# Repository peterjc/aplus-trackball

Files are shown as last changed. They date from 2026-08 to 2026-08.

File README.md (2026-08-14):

# The Ploopy A+ Trackball

The Ploopy A+ Trackball

By some stroke of luck, you've made your way here. The Ploopy A+ Trackball. Your life will never be the same.

This repository contains all of the design and production files necessary to make a Ploopy A+ Trackball. We've also included some kick-ass documentation on how to get it made, assemble it, and program it [which you can find here](https://ploopyco.github.io/aplus-trackball/).

What are you waiting for? Your new life awaits.

## QMK?!

A+ Trackballs bought from the [Ploopy store](https://ploopy.co/product-category/trackball/aplus/) come with QMK preloaded. [Check out the documentation](https://ploopyco.github.io/aplus-trackball/) for instructions on how to load new firmware onto your device. (It's super easy!)

The firmware file that ships with all A+ Trackballs is included in this repository as well, as `firmwares/aplus.uf2`.

In case you are new to the world of QMK, it is an open-source firmware for computer input peripherals. You can find the source code for all of our firmwares in [QMK's Github repository](https://github.com/ploopyco/qmk_firmware/tree/master/keyboards/ploopyco).

Note that you may have to look for specific development branches in order to find the source for all of our firmwares, as we frequently have pending pull requests.

## Under what license is this released?

As per QMK's licensing requirements, the firmware for the Ploopy A+ Trackball is released under GPLv3. Hardware design files, including electronics and mechanical files, are released under OHL CERN v2-S. Check the respective directories for full license text.

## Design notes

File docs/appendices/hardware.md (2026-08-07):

# Appendix C: Hardware

## Buying hardware from us

Getting all of the hardware on your own can be tricky because the parts you select may not fit perfectly. [That's why we sell fully-assembled A+ Trackballs](https://ploopy.co/product-category/trackball/aplus/). Here's why that's great for you:

- Everything is guaranteed to fit together perfectly
- Everything is guaranteed to work as intended
- You'll end up saving money - probably quite a bit of money - by not spending on extra parts

Your call. You'll sort it out.

## Getting your own hardware

This guide was a bit light on detail in the other sections, and that's because the hardware has to conform to many specifications. They'll all be listed here.

First, a complete list of all the hardware you'll need:

- 6x Small Screws
- 3x MR63ZZ Roller Bearings
- 2x 6700-2RS Roller Bearings
- 2x Magnet
- 4x Friction Pads
- 1x 1.75" Ball

We'll be going over all of them in detail. There will be mentions of *critical specifications*; if you're going to be sourcing your own parts, **you must get parts that conform to the critical specifications**. If you go off-menu, the parts will not fit the way that we intended when we designed the Bean. That might mean that your Bean **doesn't work**.

Let's get cracking.

### Small Screws

Here are the critical specifications:

- \#2
- 3/8" length

### MR63ZZ Roller Bearings

Here are the critical specifications:

- MR63ZZ bearing
- 3mm inner diameter
- 6mm outer diameter
- 2.5mm thickness

### 6700-2RS Roller Bearings

Here are the critical specifications:

- 6700-2RS bearing
- 10mm inner diameter
- 15mm outer diameter
- 4.0mm thickness

### Magnets

Here are the critical specifications:

- 6mm diameter
- 2mm thickness

### Friction pads

Here are the critical specifications:

- Any size
- Non-slip

### Ball

We use 1.75-inch diameter (45.00mm) balls. Any ball between 44.0mm and 46.00mm will work. Miniature snooker balls are a good aftermarket option.

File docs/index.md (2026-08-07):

# Home

So, you want to build a Ploopy A+ Trackball, eh? Or, maybe you want to replace some broken parts. Maybe you want to reprogram it. Or maybe you just want to know how it all works. No matter the motivation, this is the place to learn.

**Sourced the parts and itching to get it built?** --> Get started by going to the [assembly instructions](assembly-instructions.md).

**Looking to purchase your own A+ Trackball?** --> [Check out the Ploopy store](https://ploopy.co/product-category/trackball/aplus/).

**Building a Ploopy A+ Trackball from scratch?** --> Get started by going to [Appendix A: Printed circuit boards](appendices/pcbs.md).

---

*Copyright (C) 2026 Ploopy Corporation. Permission is granted to copy, distribute and/or modify this document under the terms of the GNU Free Documentation License, Version 1.3 or any later version published by the Free Software Foundation; with no Invariant Sections, no Front-Cover Texts, and no Back-Cover Texts. A copy of the license is included in the section entitled "GNU Free Documentation License".*

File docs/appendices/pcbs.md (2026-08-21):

# Appendix A: Printed circuit boards

## Buying boards from us

Getting the Ploopy boards made can be complex, and expensive, especially if you only need one set. [That's why we sell fully-assembled A+ Trackballs](https://ploopy.co/product-category/trackball/aplus/). Here's why that's great for you:

- You get a PCB with all components soldered
- The firmware is already programmed on the microcontroller, so you won't have to program it
- It'll cost a hell of a lot less than if you do a production run of PCBs just for yourself
- You won't have to order components and wait while they come in
- We guarantee that it works

Just something to consider. You're smart. You'll figure it out.

## Making your own boards

Want to make your own Ploopy A+ Trackball boards? Great! Less work for us. Seriously, though, only choose this option if you know what you're doing. You don't want to embarrass yourself, do you?

### Step 1: Order the PCBs from a PCB production company

Here are the most important configurations you'll need to communicate to the company:

- 4 layers
- FR-4, TG 150-160 (basically, whatever the cheapest option is)
- 0.8mm thickness
- 6/6mil track/spacing distance
- 0.3mm minimum hole size
- ENIG surface finish, but you can go with HASL if you don't care about lead poisoning
- 1oz copper thickness for both outer and inner layers
- Choose whatever colours you want for solder mask and silkscreen; we like green solder mask and white silkscreen

If something is missing from here, it's not really important.

At some point, you'll have to upload design files to the production company. Use the [electronics source files](https://github.com/ploopyco/aplus-trackball/tree/main/hardware/electronics) to generate manufacturing files (you'll have to convert them from their native Altium format if you're using some other platform). That should contain everything you need to get the boards made. If the production company rejects this package, however, you'll need to address the issue yourself.

### Step 2: Order the electronics components

All of the components are described in the schematics of the PCBs. Ordering the components is left as an exercise for the reader.

A complete list of all of the components can be found in the electrical design files.

### Step 3: Get the necessary tools

- PCB
- All of the electronics components
- A hot air rework tool
- Solder paste
- A printout of the schematics

### Step 4: Solder the components to the boards

Once you've got the PCBs and all of the components, print out the schematics. Use the schematics to match the reference designators on the PCBs to the reference designators on the schematics, and then get to soldering.

If you've never soldered surface mount components before, or want a refresher on how to solder, we recommend [this video on using an iron to solder surface mount components](https://www.youtube.com/watch?v=3NN7UGWYmBY), and [this video on using a hot-air soldering station](https://www.youtube.com/watch?v=c_Qt5CtUlqY).

### Step 5: All done!

Congrats, you finished assembling the electronics! Pat yourself on the back.

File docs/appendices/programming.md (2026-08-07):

# Appendix D: QMK Firmware Programming

## Working with QMK

Ploopy devices are fairly easy to program and reprogram, thanks to the excellent work by all of the developers and maintainers of the [QMK firmware suite](https://github.com/qmk/qmk_firmware).

## Before you begin

If you have never used QMK before, go through [all of the steps in the QMK guide to set up your environment](https://docs.qmk.fm/#/newbs_getting_started).

QMK was built for keyboards, so you'll see lots of references to code that looks like the following:

`-kb <keyboard>`

Whenever you see that, use the following syntax:

`-kb ploopyco/aplus`

and you'll be fine.

## Building the Ploopy device firmware

Using QMK MSYS or your compilation toolchain of choice, compile the firmware with the following command:

`qmk compile -kb ploopyco/aplus/rev1_001 -km default`

For more details on building QMK firmware in general, see the [QMK firmware guide](https://docs.qmk.fm/#/newbs_building_firmware).

## Putting the Ploopy device into bootloader mode

Under normal circumstances, the device can be put into bootloader mode with a special startup procedure.

1. Identify the "bootloader" button on the device's keymap. [The default keymap is available here](manual.md#default-keymap).
2. Unplug the device.
3. Hold down the "bootloader" button.
4. Plug in the device.
5. The computer should recognise that a mass storage device was just plugged in. Once this is done, you should be able to drag and drop files onto the Ploopy device, as if the board was a USB drive.

And that's it. While plugged in this way, the Ploopy device will accept new firmware.

If you want to upload a new firmware file (a ".uf2" file, like "ploopy_aplus_v42069" or something), just drag it into the folder, and it'll automatically install on the Ploopy device and restart itself.

## Putting the Ploopy device into bootloader mode if the device is bricked

If the device cannot be put into bootloader mode using the above procedure, there is another procedure that can be used to force the device into bootloader mode. However, it involves opening the device and is more involved.

1. Unplug it from your computer.
2. Open it by removing the screws in the Base and removing the Top.
3. Look for a pair of vias (gold-plated holes) on the board. Here's a photo for reference:

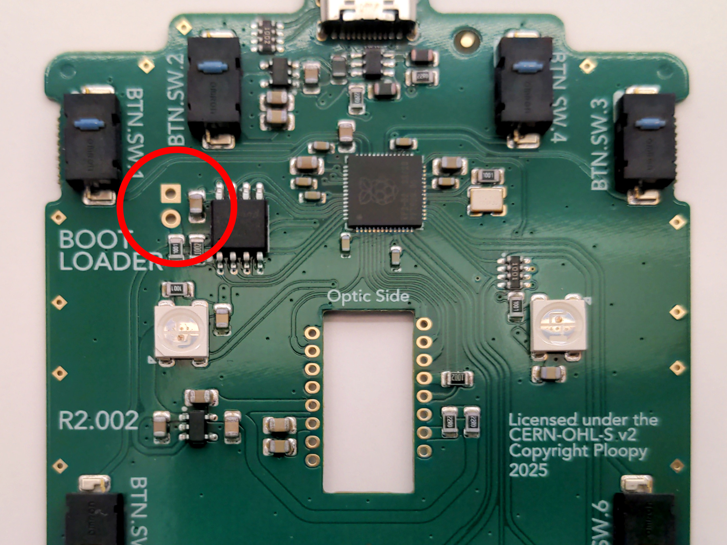
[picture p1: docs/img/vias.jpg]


4. Get a paper clip (non-insulated, i.e. no plastic covering it) or a pair of tweezers, or some wire. Whatever you've got on hand that's metal.
5. Stick the paper clip or tweezers into the holes. You're trying to form an electrical connection between the two holes.
6. While you've got the two vias connected with your metal bridge, plug the Ploopy device into your computer.
7. The computer should recognise that a mass storage device was just plugged in. Once this is done, you should be able to drag and drop files onto the Ploopy device, as if the board was a USB drive. Feel free to remove the tweezers or paperclip at this point.

And that's it. While plugged in this way, the Ploopy device will accept new firmware.

If you want to upload a new firmware file (a ".uf2" file, like "ploopy_aplus_v42069" or something), just drag it into the folder, and it'll automatically install on the Ploopy device and restart itself.

Whenever you want to put new firmware onto the Ploopy device, go through these steps again.

**TIP**: If your firmware is in some kind of strange state and uploading new firmware isn't fixing it, try uploading [a flash nuke](https://learn.adafruit.com/getting-started-with-raspberry-pi-pico-circuitpython/circuitpython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) to the bean before flashing the new firmware. It wipes the memory of the bean completely clean, which can help clear a few types of errors.

## And that's it!

Happy customizing!

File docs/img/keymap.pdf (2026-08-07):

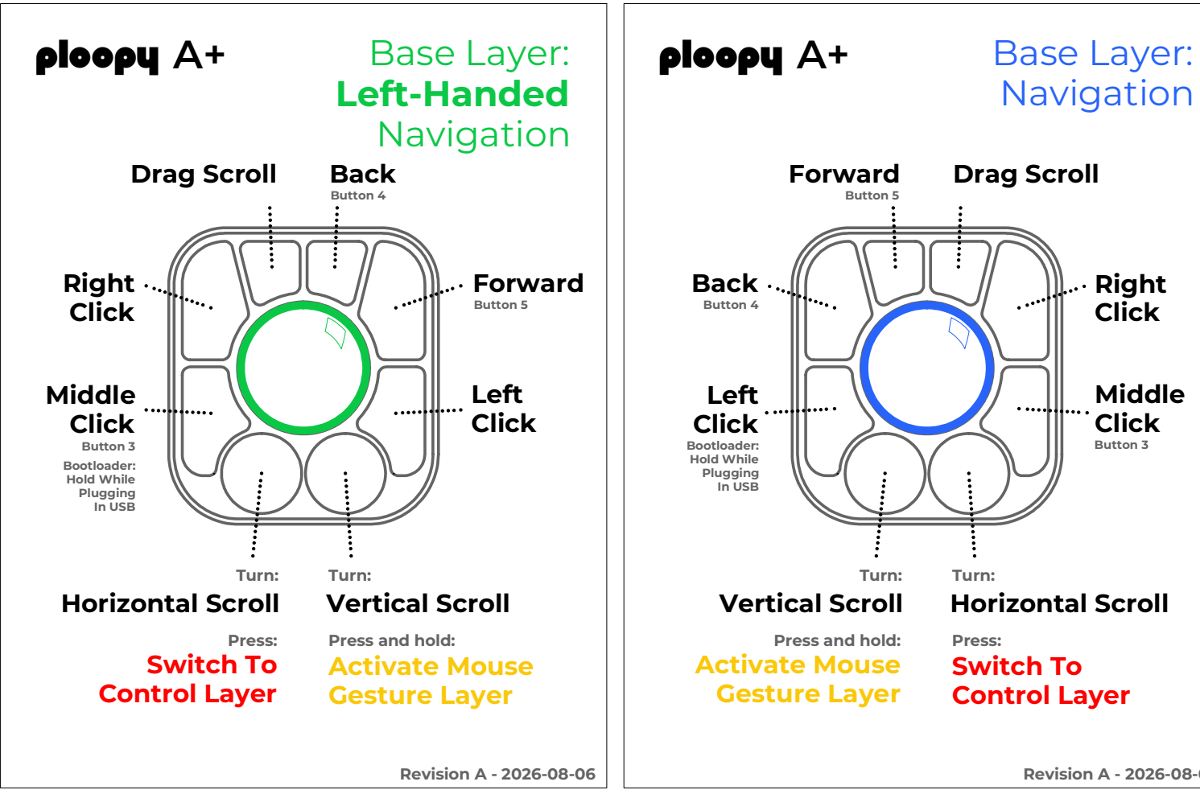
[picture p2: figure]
Bootloader: Hold While Plugging In USB; Left Click; Right Click; Middle Click; Button 3; Drag Scroll; Vertical Scroll; Horizontal Scroll; Switch To Control Layer; Press and hold:; Turn:; ploopy A+; Forward; Button 5; Back; Button 4; Base Layer:; Navigation; Left-Handed; Press:; Activate Mouse Gesture Layer
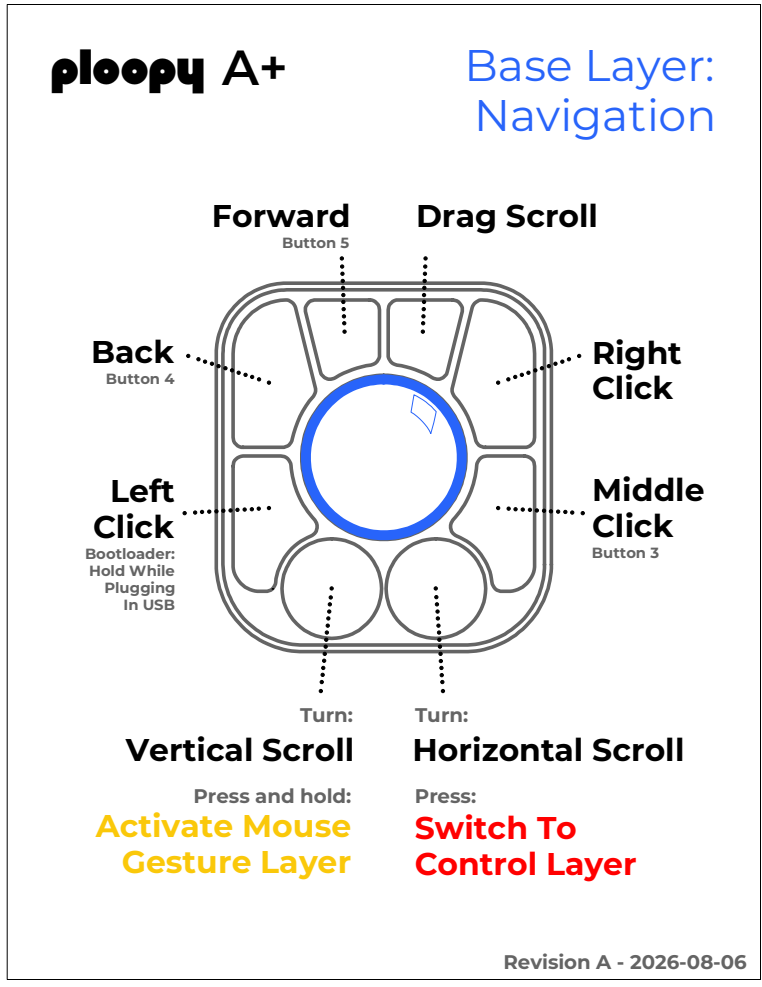
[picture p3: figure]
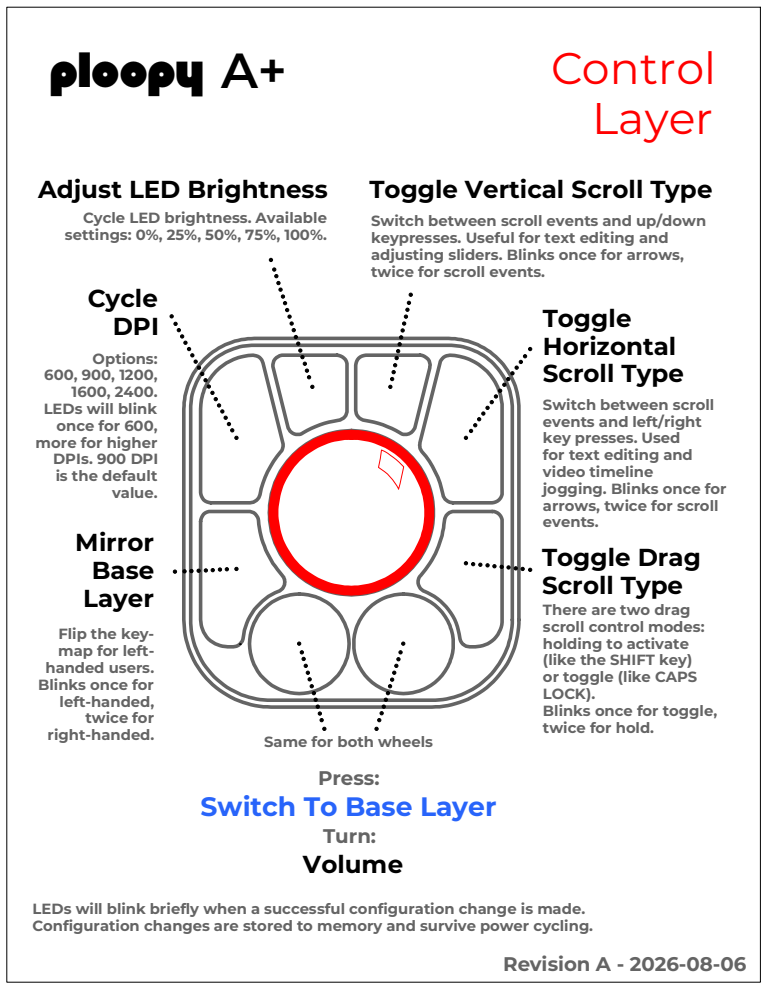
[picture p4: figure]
Cycle DPI; Options: 600, 900, 1200, 1600, 2400. LEDs will blink once for 600, more for higher DPIs. 900 DPI is the default value. Mirror Base Layer; Flip the key- map for left- handed users. Blinks once for left-handed, twice for right-handed.; Revision A - 2026-08-06; Same for both wheels Press: Switch To Base Layer; Volume; Turn:; Toggle Drag Scroll Type; There are two drag scroll control modes: holding to activate (like the SHIFT key) or toggle (like CAPS LOCK). Blinks once for toggle, twice for hold.; Toggle Horizontal Scroll Type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

LEDs will blink briefly when a successful configuration change is made. Configuration changes are stored to memory and survive power cycling.

Revision A - 2026-08-06 | Revision A - 2026-08-06
Adjust LED Brightness | Toggle Vertical Scroll Type Switch between scroll events and up/down adjusting sliders. Blinks once for arrows,

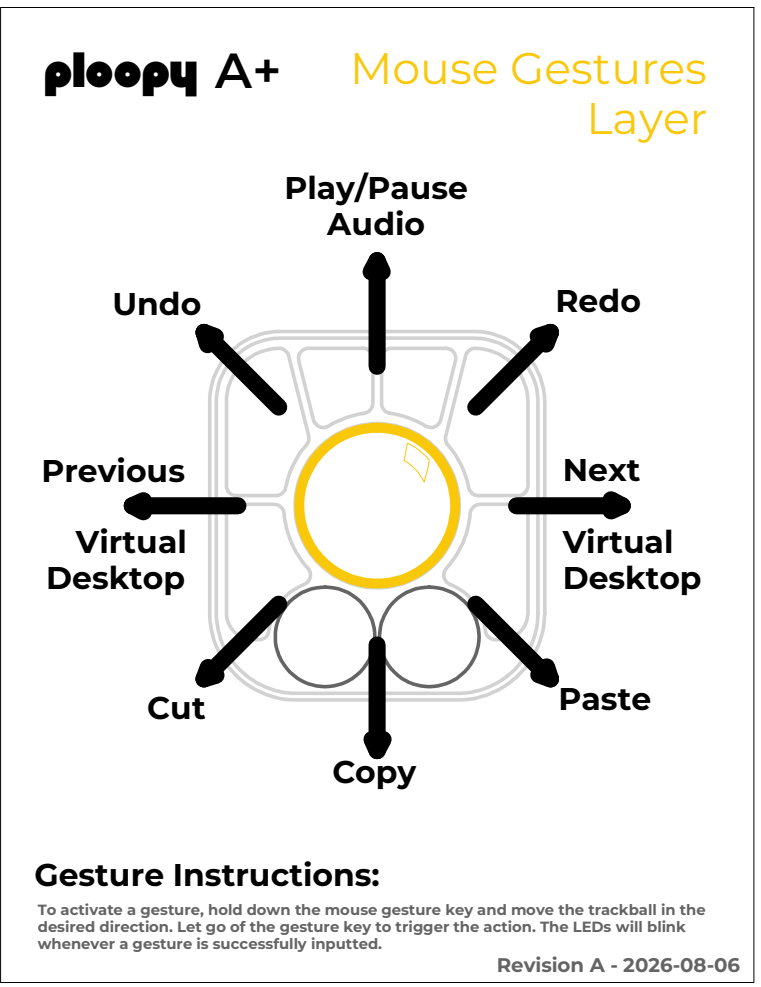
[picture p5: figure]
Revision A - 2026-08-06; Gesture Instructions:; Cut; Copy; Undo; Redo; Paste; ploopy A+; Previous; Virtual Desktop; Next; Play/Pause Audio; Mouse Gestures Layer

To activate a gesture, hold down the mouse gesture key and move the trackball in the desired direction. Let go of the gesture key to trigger the action. The LEDs will blink whenever a gesture is successfully inputted.

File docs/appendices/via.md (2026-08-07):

# Appendix F: Using VIA

The A+ Trackball's keymap can be customized using a web application called "VIA". This allows for easy and portable customization of the A+'s buttons.

Currently, a bit of additional work is necessary to get VIA to work, but it should only take about thirty seconds.

Begin by copying and pasting the following into a text file, saving it as *aplus.json*:

    {
      "name": "Ploopy A+ Trackball",
      "vendorId": "0x5043",
      "productId": "0x81DB",
      "matrix": {
        "rows": 1,
        "cols": 8
      },
      "customKeycodes": [
        {
          "name": "DPI Config",
          "title": "DPI Config",
          "shortName": "DPI"
        },
        {
          "name": "Drag Scroll",
          "title": "Drag Scroll",
          "shortName": "DragScl"
        }
      ],
      "layouts": {
        "keymap": [
          [
            {
              "h": 2
            },
            "0,1",
            {
              "x": 0.25,
              "h": 1.25
            },
            "0,2",
            {
              "x": 0.25,
              "h": 1.25
            },
            "0,3",
            {
              "x": 0.25,
              "h": 2
            },
            "0,4"
          ],
          [
            {
              "y": 1.25,
              "w": 1.75,
              "h": 2
            },
            "0,0",
            {
              "x": 1.25,
              "w": 1.75,
              "h": 2
            },
            "0,5"
          ],
          [
            {
              "x": 0.5,
              "y": 1.25,
              "w": 1.5,
              "h": 1.5
            },
            "0,7",
            {
              "x": 0.75,
              "w": 1.5,
              "h": 1.5
            },
            "0,6"
          ]
        ]
      }
    }

- Next, navigate to [the VIA web app](https://usevia.app), using **Microsoft Edge, Chrome, or Opera**. Any other browser that supports WebHID will work, too.
- Look at the top toolbar of the web application, and click the tab called *DESIGN*.
- Uncheck *Use V2 definitions (deprecated)*.
- Click *Load* and upload the *aplus.json* file that you saved on your computer.
- Plug in the A+ if it wasn't plugged in already.
- Look at the top toolbar of the web application, and click the tab called *CONFIGURE*.
- Click *Authorize Device*. A modal window should pop up, and you should see the *Ploopy A+ Trackball* as an option to connect. Do so now.

You should now see a representation of the buttons of the A+ in the web app. You are now free to modify the button's functionality.

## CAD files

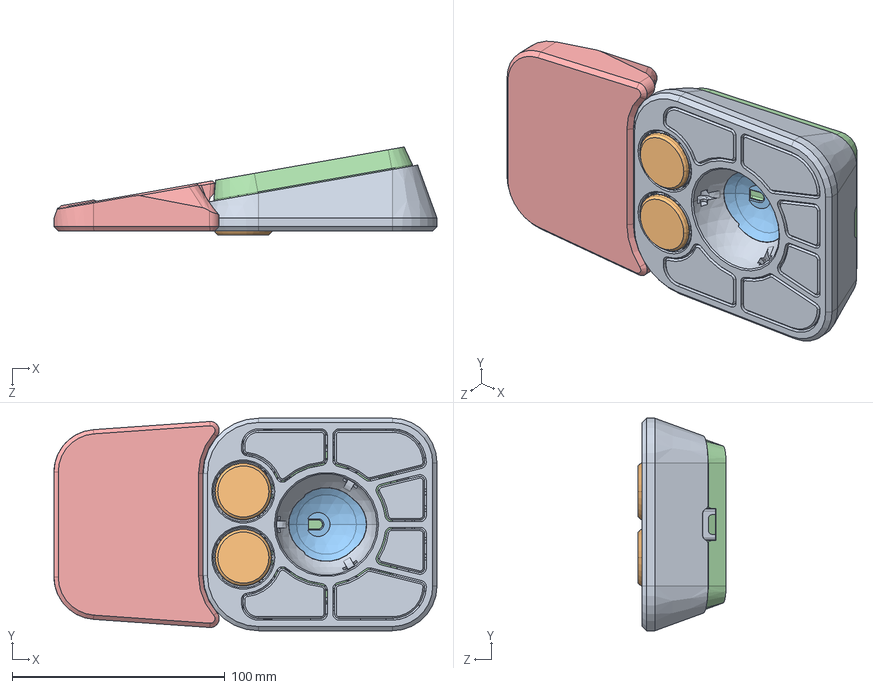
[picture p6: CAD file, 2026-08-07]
hardware/mechanicals/Aplus-RevA-NoLogo.STEP
180.2 x 100.0 x 41.5 mm

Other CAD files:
hardware/mechanicals/Aplus-RevA-NoLogo.STL

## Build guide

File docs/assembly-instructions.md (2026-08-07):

<style>
  .tooltip {
    padding: 15px;
    border-radius: 5px;
    margin-bottom: 10px;
    display: flex;
    align-items: center;
  }

  .tooltip .icon {
    font-size: 1rem;
    margin-right: 10px;
  }

  .tip {
    background-color: #fcf003;
    color: #333;
  }

  .warning {
    background-color: #ffb3b3;
    color: #333;
  }

  .info {
    background-color: #cce5ff;
    color: #004085;
  }

  .info a {
    color: #004085;
    font-weight: bold;
    text-decoration: underline;
  }
</style>

## Step 1: Prepare necessary tools

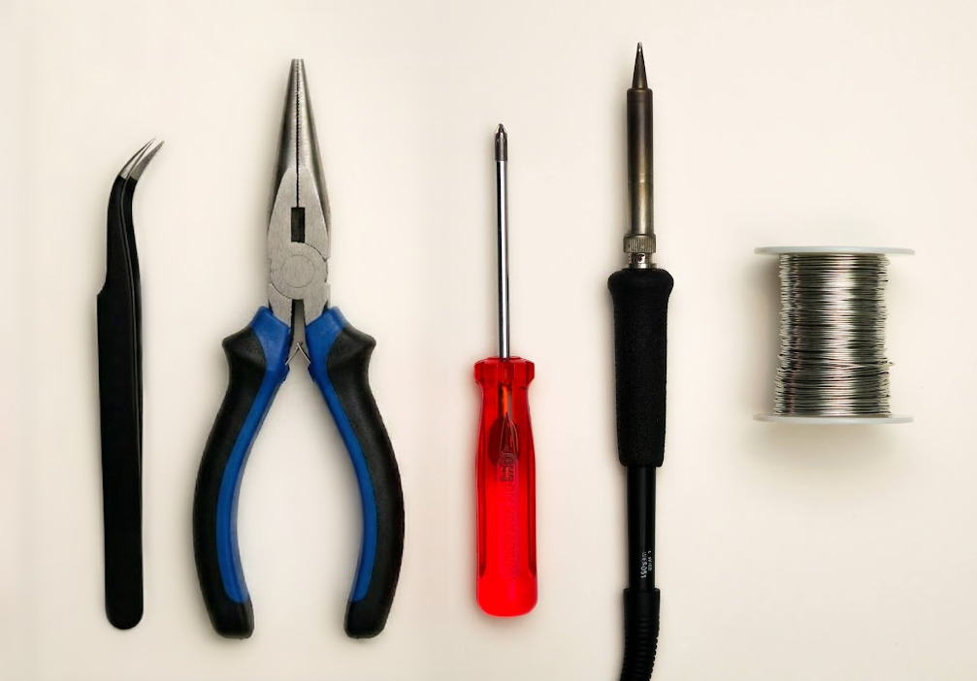
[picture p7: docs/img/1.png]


- A #1 Phillips head screwdriver
- Soldering iron
- Solder
- Optional: tweezers
- Needle-nose pliers

<div class="tooltip tip">
  <span class="icon">💡</span>
  <span><strong>Tip:</strong> A similar smallish Phillips head screwdriver could work.</span>
</div>

## Step 2: Prepare parts for PCB soldering

Prepare the following components as pictured below:

- Printed circuit board
- PMW-3360 chip

<div class="tooltip tip">
  <span class="icon">💡</span>
  <span><strong>Tip:</strong> The PMW-3360 chip will come in a small piece of foam. Go ahead and remove it now.</span>
</div>

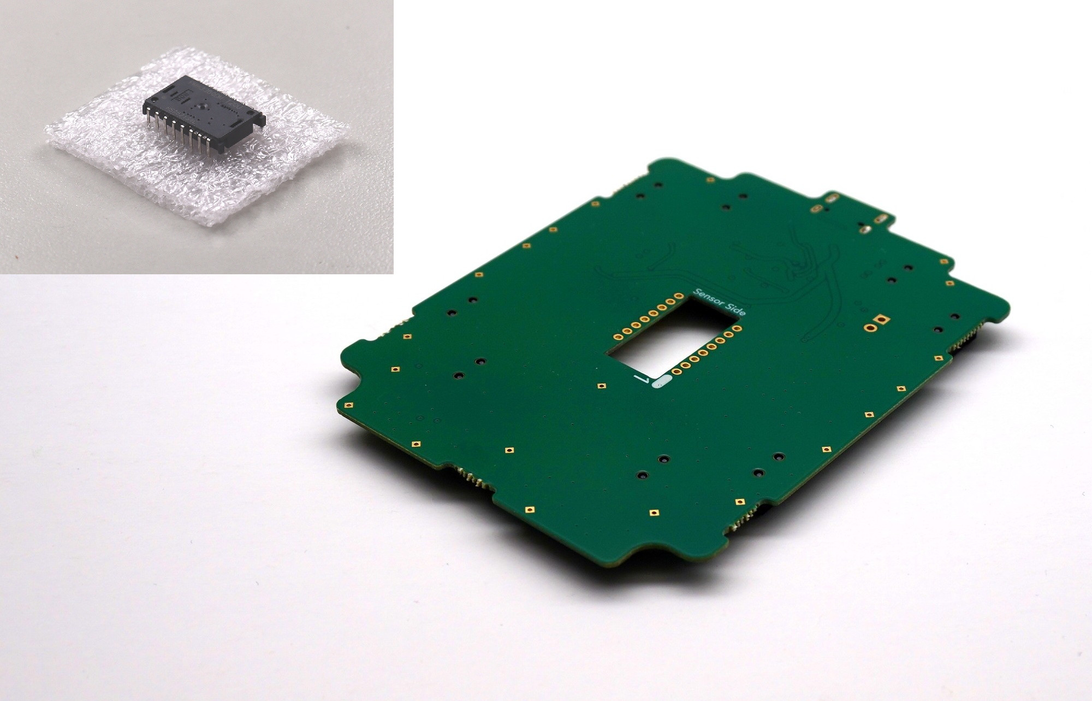
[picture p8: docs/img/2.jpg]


## Step 3: Solder PMW-3360 sensor to printed circuit board

- Place the sensor onto the circuit board, ensuring the orientation is correct.

<div class="tooltip warning">
  <span class="icon">🚨</span>
  <span><strong>Warning:</strong> Use the cues presented in the following images to ensure the sensor is oriented correctly.</span>
</div>

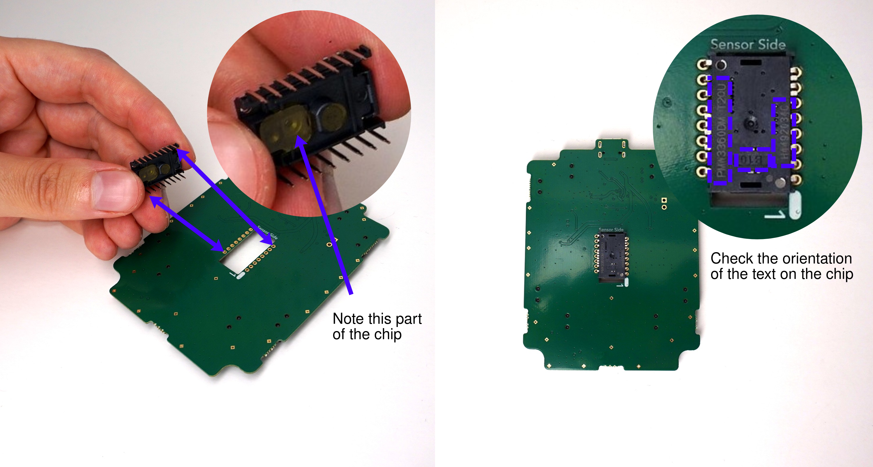
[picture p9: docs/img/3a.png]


<div class="tooltip warning">
  <span class="icon">🚨</span>
  <span><strong>Warning:</strong> The sensor must be flat down as far as it can possibly slide into the holes before soldering.</span>
</div>

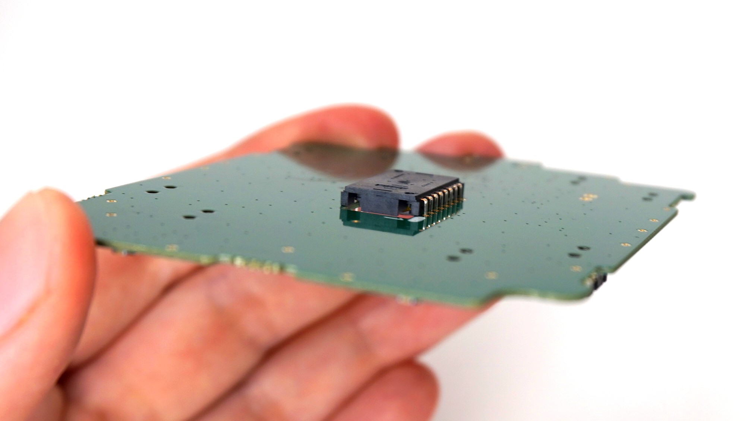
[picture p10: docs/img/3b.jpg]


## Step 4: Remove the tab of kapton tape on the PMW-3360 chip

<div class="tooltip tip">
  <span class="icon">💡</span>
  <span><strong>Tip:</strong> Try to do this step in a dust-free environment.</span>
</div>

- There are two small tabs of orange tape covering the sensor's main holes. Remove them now.

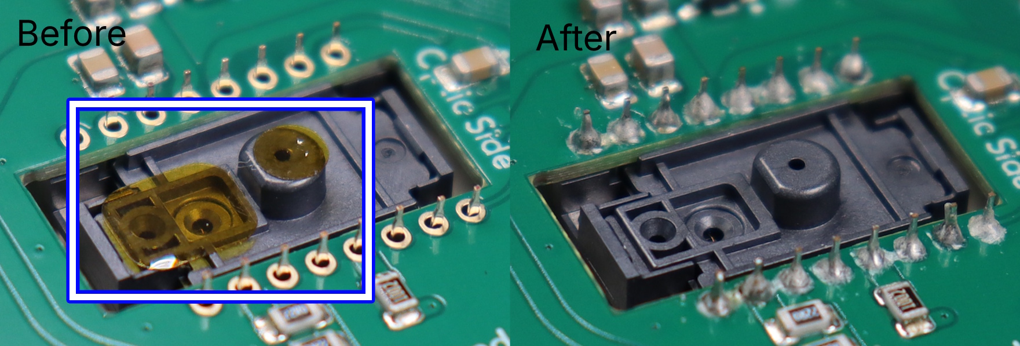
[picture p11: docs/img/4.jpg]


<div class="tooltip info">
  <span class="icon">ℹ️</span>
  <span><strong>Info:</strong> Check your solder joints during this step to ensure that they are good. To know if they are good, consult the
    <a href="https://help.ploopy.co/?docs=ive-soldered-my-kit-together-but-the-parts-i-soldered-dont-work-2">soldering FAQ</a>.</span>
</div>

## Step 5: Attach the PMW-3360 optic to the PMW-3360 chip

- Orient the optic as shown in the image before insertion.

<div class="tooltip warning">
  <span class="icon">🚨</span>
  <span><strong>Warning:</strong> It should NOT require any force to insert fully; if it does, remove it and check the orientation before trying again.</span>
</div>

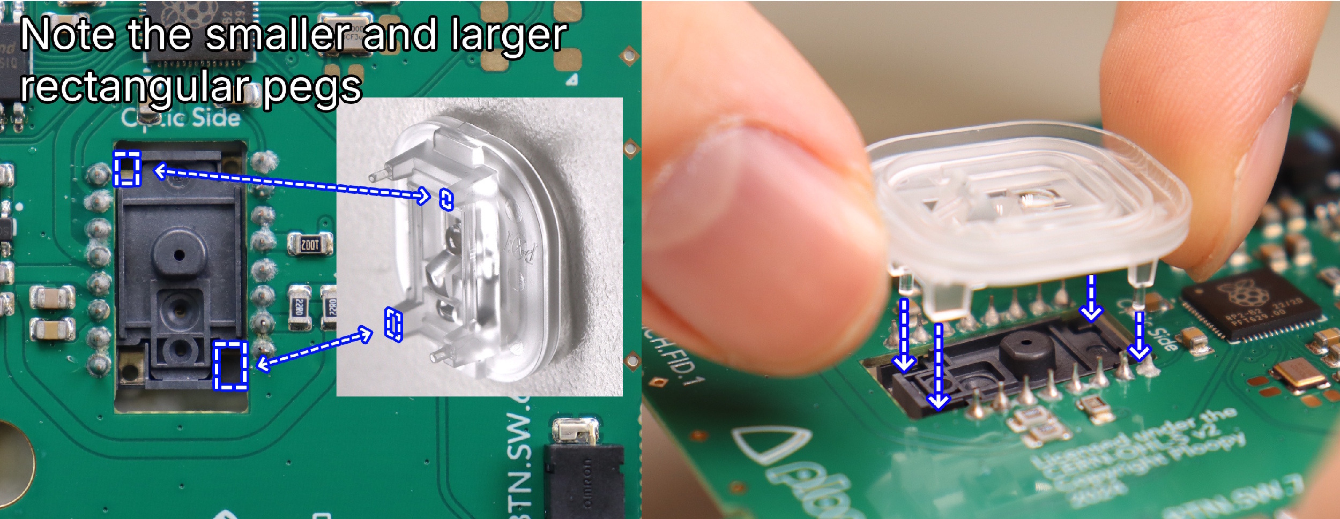
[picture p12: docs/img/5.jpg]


## Step 6: Place the PCB into the Base

- The PCB should not require force to insert into the Base.

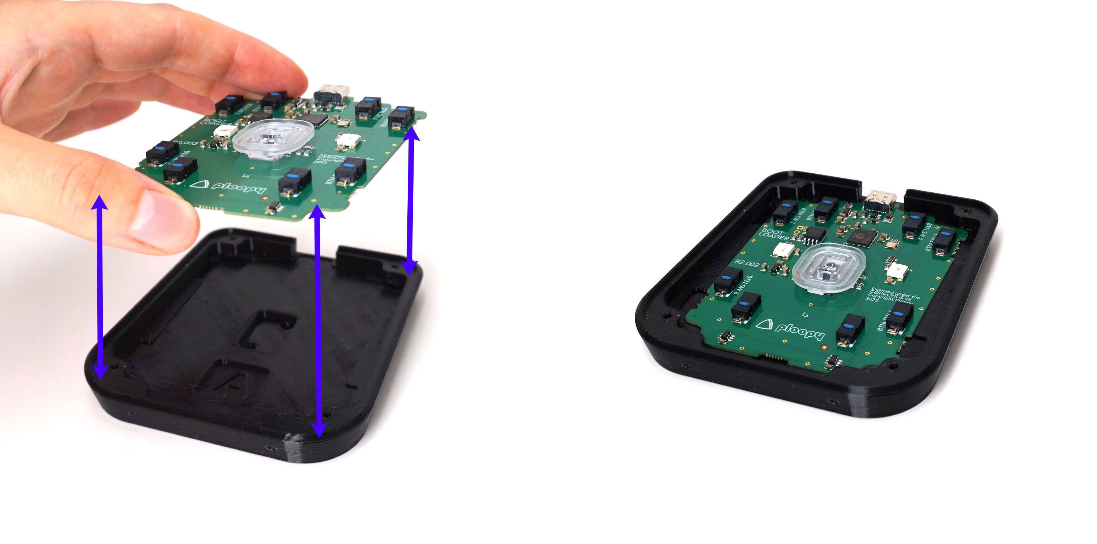
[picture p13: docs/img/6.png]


## Step 7: Place the Sensor Cap on the PCB

- Place the Sensor Cap on the PCB as shown in the image.

<div class="tooltip tip">
  <span class="icon">💡</span>
  <span><strong>Tip:</strong> The Sensor Cap doesn't snap onto the PMW-3360 optic. It "floats" on top of the optic for now. Once fully assembled, the Sensor Cap will be securely held down.</span>
</div>

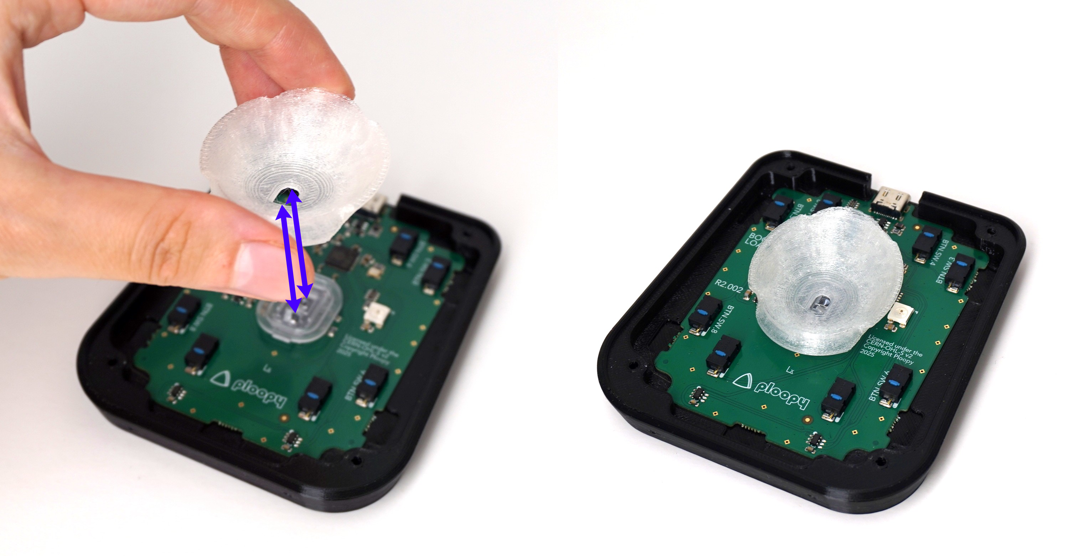
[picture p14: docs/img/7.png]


## Step 8: Insert one magnet into one Knob

<div class="tooltip tip">
  <span class="icon">💡</span>
  <span><strong>Tip:</strong> The orientation of the first magnet does not matter. Insert the magnet into either hole, in any direction it will fit.</span>
</div>

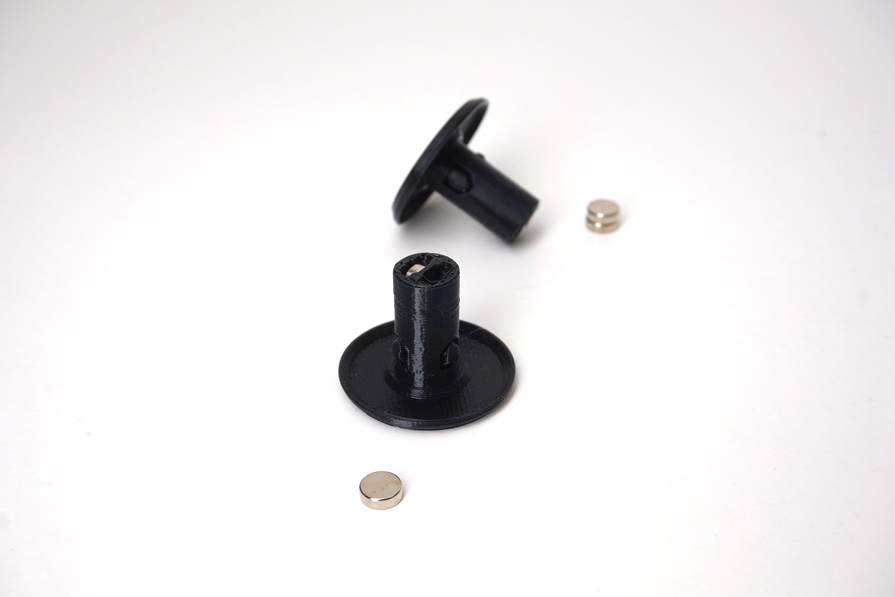
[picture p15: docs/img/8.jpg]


## Step 9: Align second magnet correctly

<div class="tooltip warning">
  <span class="icon">🚨</span>
  <span><strong>Warning:</strong> If the magnet is not aligned correctly, the Knob will not function, and the magnets are <strong>very</strong> difficult to remove!</span>
</div>

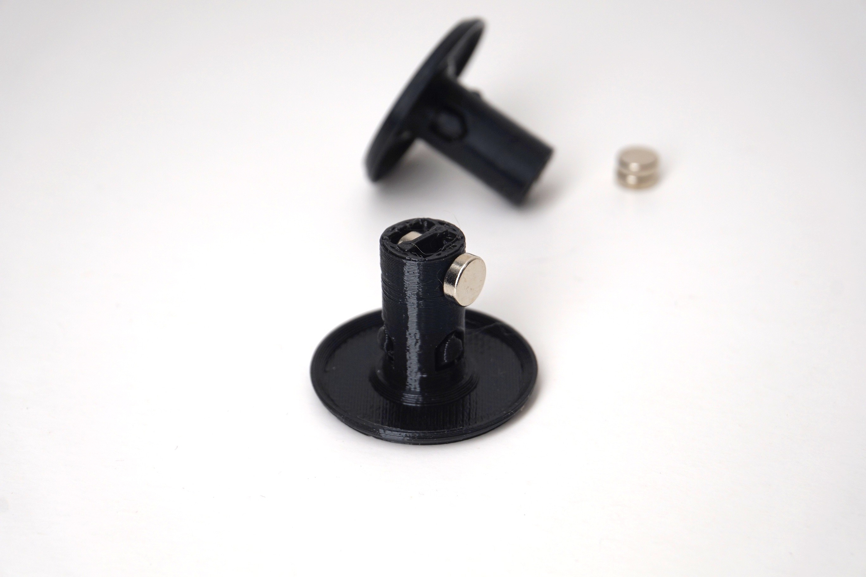
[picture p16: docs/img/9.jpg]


## Step 10: Insert second magnet

<div class="tooltip tip">
  <span class="icon">💡</span>
  <span><strong>Tip:</strong> If the second magnet is oriented correctly, the first magnet will try to pull it into the hole. If the magnet is not oriented correctly, the first magnet will try to repel it out of the hole.</span>
</div>

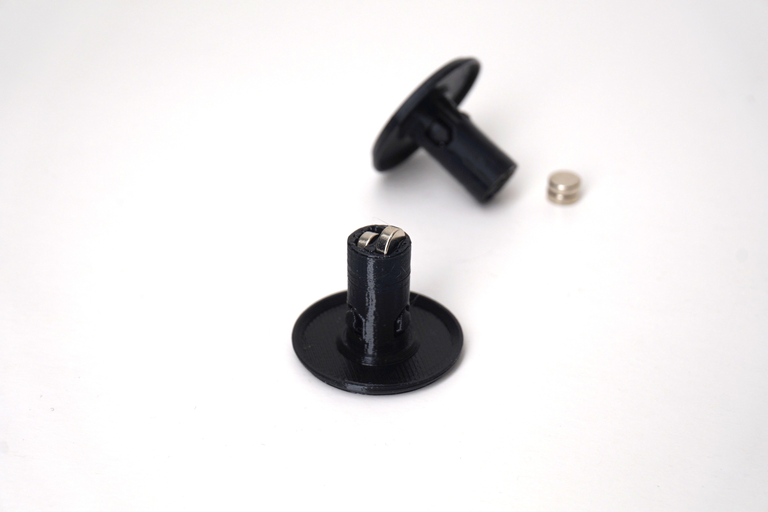
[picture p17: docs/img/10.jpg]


## Step 11: Slip large bearing onto Knob shaft

<div class="tooltip tip">
  <span class="icon">💡</span>
  <span><strong>Tip:</strong> This may require some force.</span>
</div>

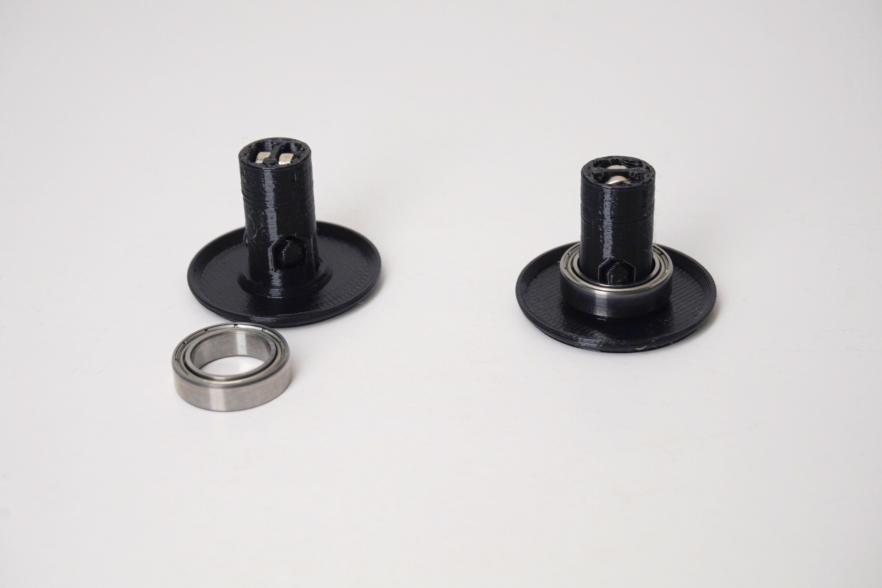
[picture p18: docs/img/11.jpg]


## Step 12: Repeat Steps 8-11 for the second Knob

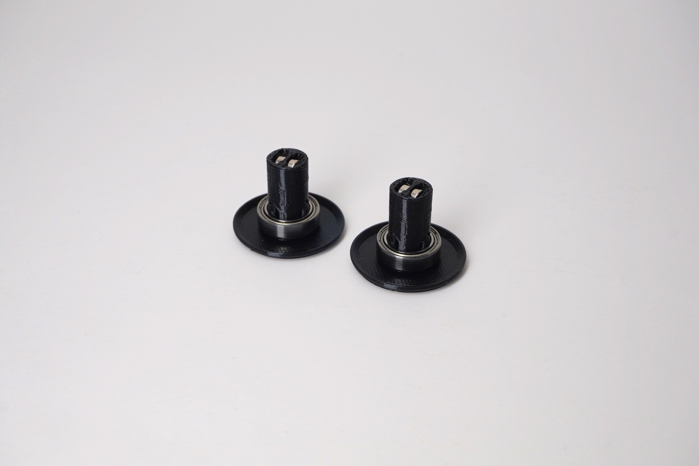
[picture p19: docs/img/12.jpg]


## Step 13: Insert Knobs into Top

<div class="tooltip tip">
  <span class="icon">💡</span>
  <span><strong>Tip:</strong> This may require some force.</span>
</div>

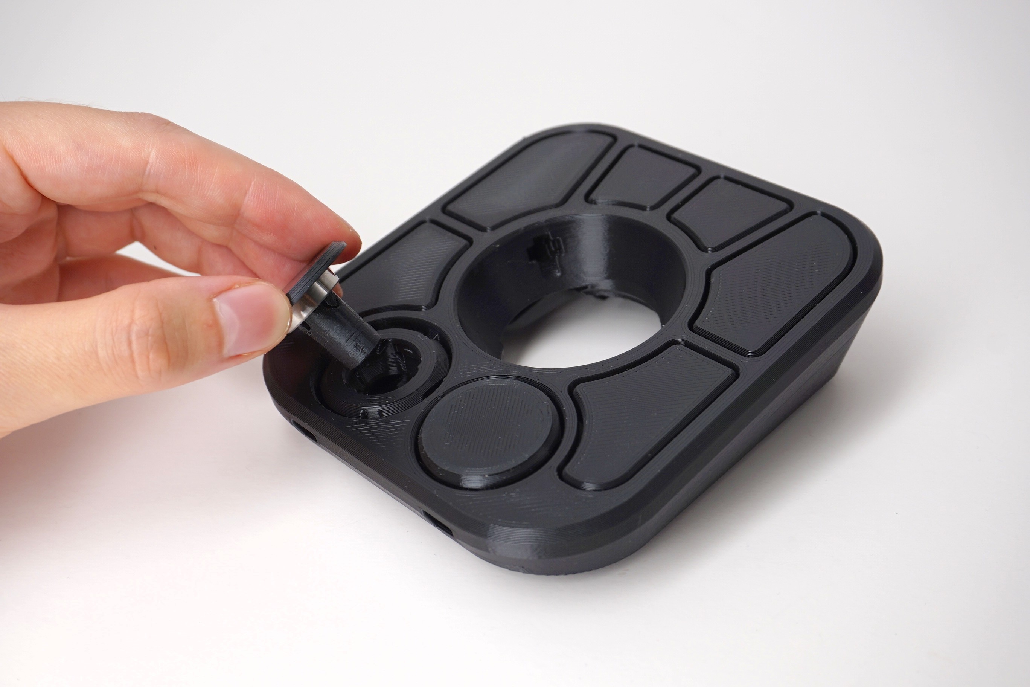
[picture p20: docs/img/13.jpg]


## Step 14: Place the Top onto the Base

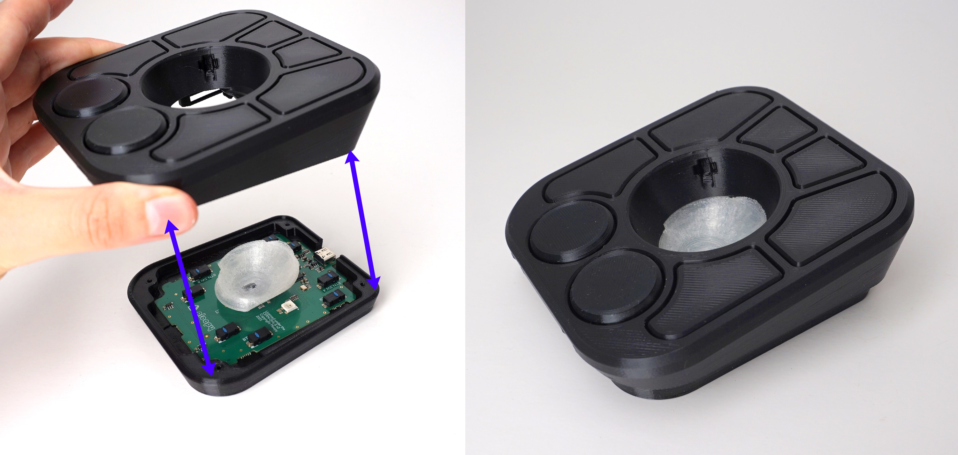
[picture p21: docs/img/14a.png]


<div class="tooltip tip">
  <span class="icon">💡</span>
  <span><strong>Tip:</strong> If necessary, adjust the position of the Sensor Cap as you're lowering the Top onto the Base. It should end up looking like the image.</span>
</div>

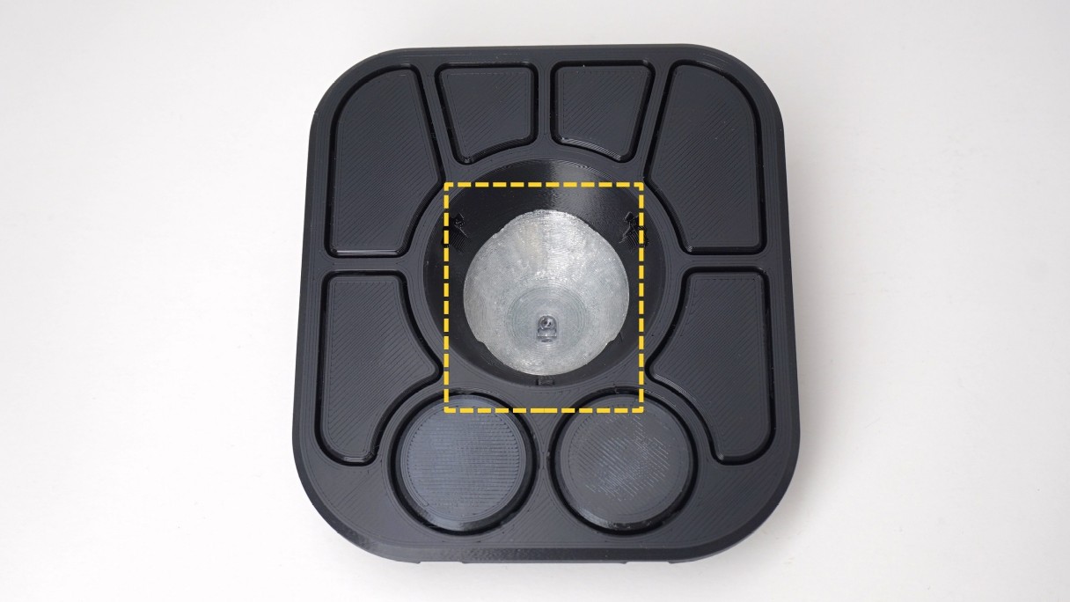
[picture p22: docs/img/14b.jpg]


## Step 15: Screw the Base into the Top

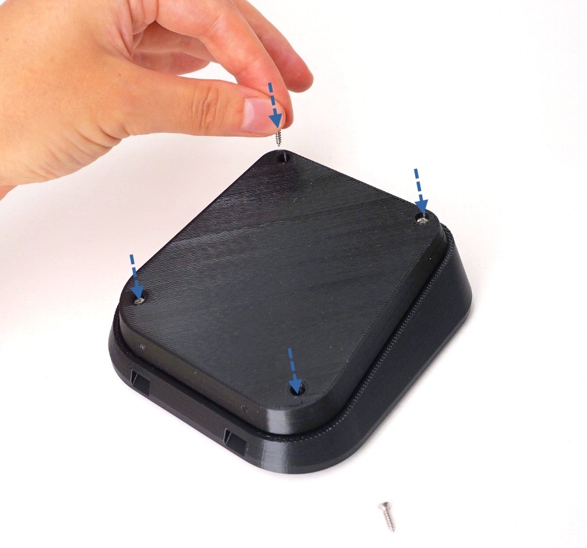
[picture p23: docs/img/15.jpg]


<div class="tooltip tip">
  <span class="icon">💡</span>
  <span><strong>Tip:</strong> Only screw until the frame feels firmly together. If you use too much force, you may break the frame.</span>
</div>

## Step 16: Prepare Roller Bearing Parts

- 3x Roller Bearing
- 3x Roller Bearing Dowel
- Bearing Press Jig (Taller Half + Shorter Half)

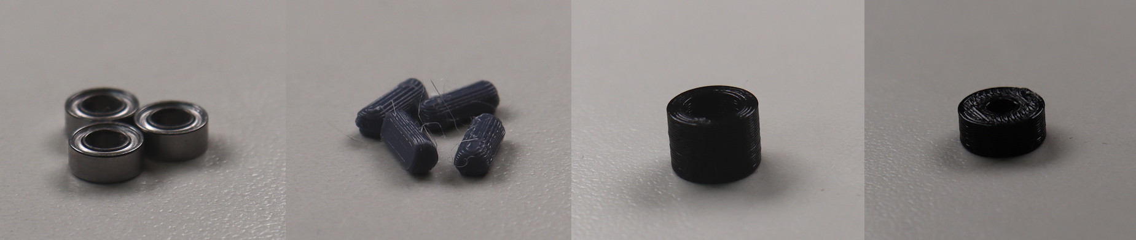
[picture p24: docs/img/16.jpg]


## Step 17: Insert Roller Bearing and Bearing Dowel into Bearing Press Jig

- Insert the bearing into the taller half of the bearing press jig.

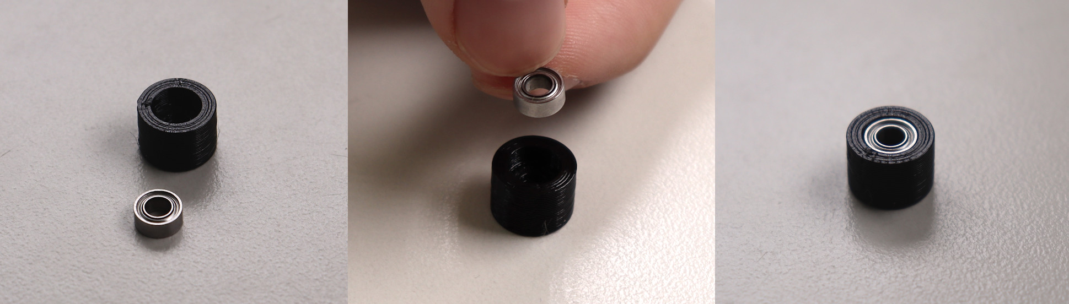
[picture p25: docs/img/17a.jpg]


- Insert dowel into the shorter half of the bearing press jig.

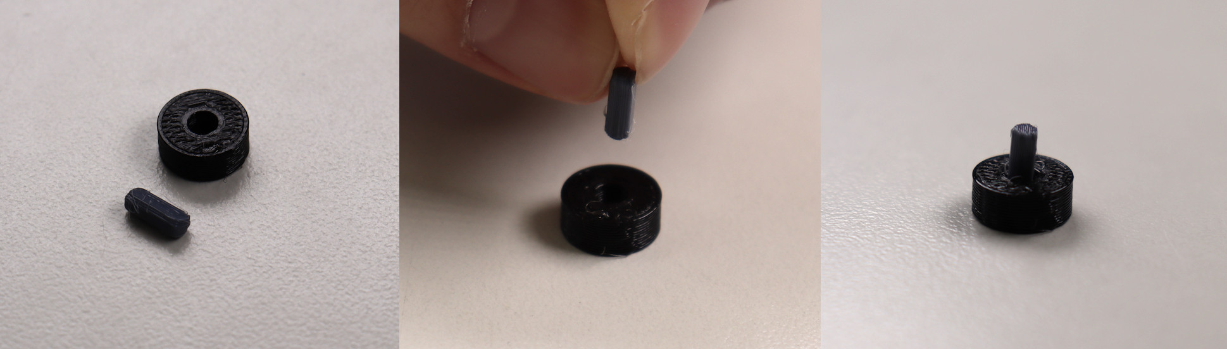
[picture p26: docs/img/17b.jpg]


## Step 18: Press the Bearing Jig Together

<div class="tooltip tip">
  <span class="icon">💡</span>
  <span><strong>Tip:</strong> This may require a surprising amount of force; try your best not to bend the roller bearing dowel. If you do, there are spares included in the kit.</span>
</div>

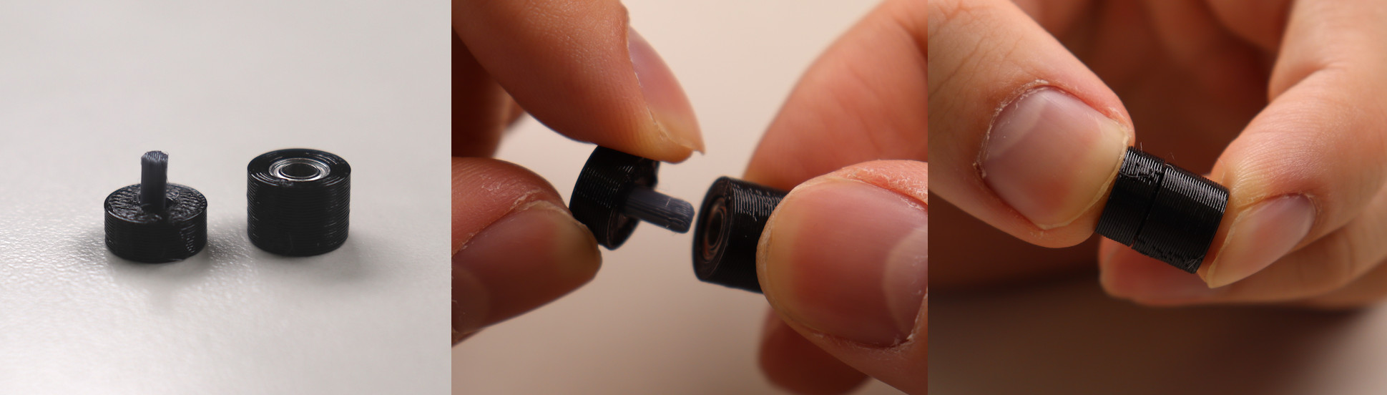
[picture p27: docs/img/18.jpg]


## Step 19: Remove roller bearing from bearing press jig and repeat

- Remove the the roller bearing from the press jig.
- Repeat 3 times to end with 3 roller bearings.

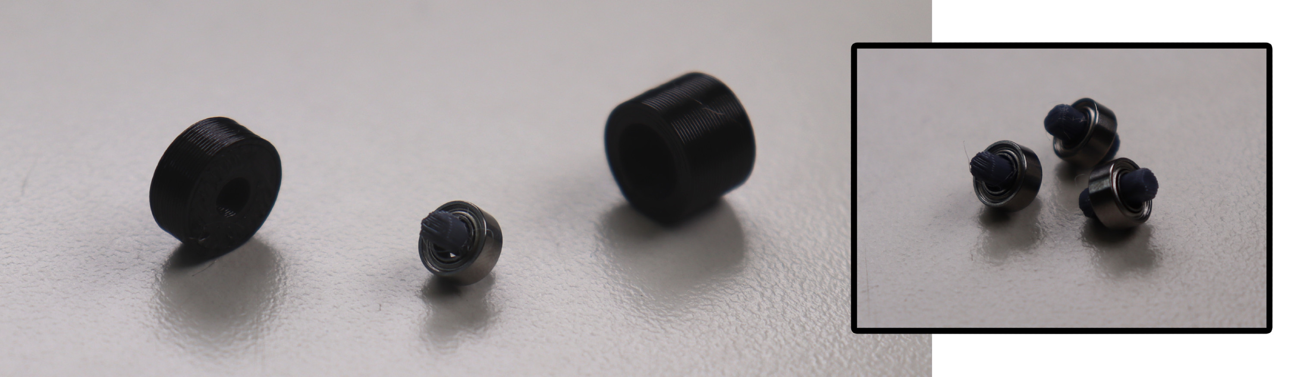
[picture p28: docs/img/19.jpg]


## Step 20: Insert roller bearings into the Top

- Insert the roller bearings into the 3 holes in the top of the frame.
- Ensure the bearings are pressed all the way into the case.

<div class="tooltip tip">
  <span class="icon">💡</span>
  <span><strong>Tip:</strong> Needle nose pliers or some similar tool can be used to ensure that the bearing is fully seated.</span>
</div>

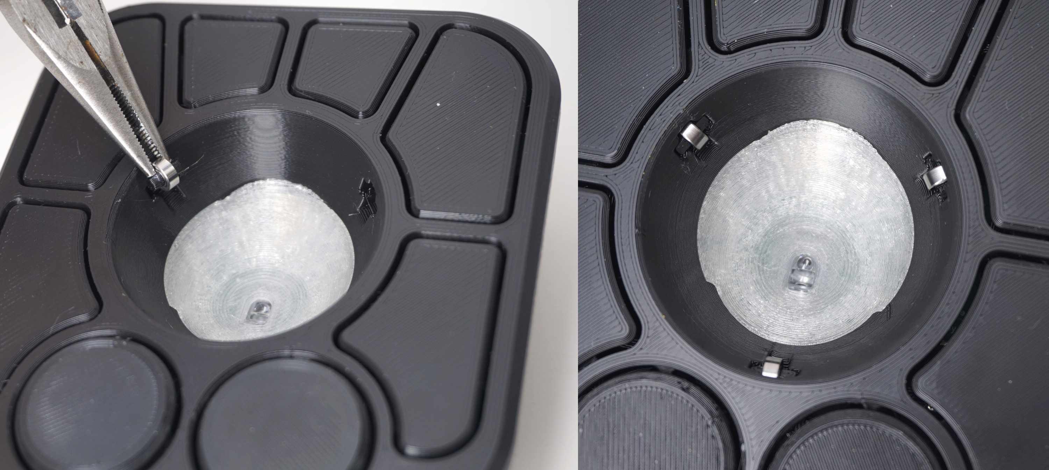
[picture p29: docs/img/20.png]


## Step 21: Place Friction Pads on Base

- Flip the adept frame upside down.
- Place the friction pads on each corner of the frame.

<div class="tooltip tip">
  <span class="icon">💡</span>
  <span><strong>Tip:</strong> Do not cover the screw holes with the friction pads, as this will make opening the case more difficult in the future.</span>
</div>

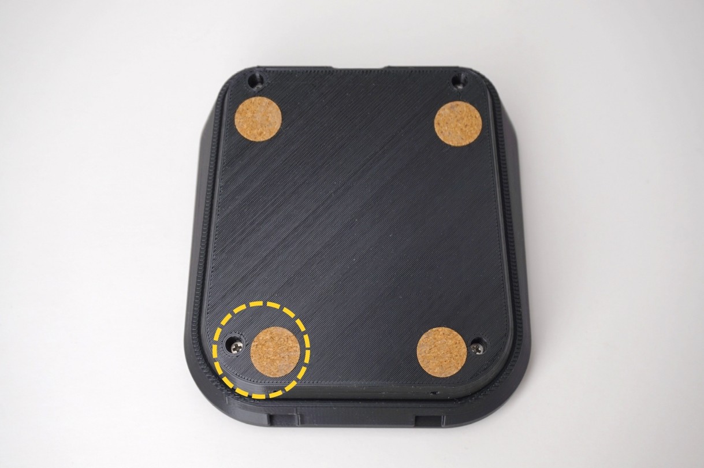
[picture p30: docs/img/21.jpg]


## Step 22: Insert the ball

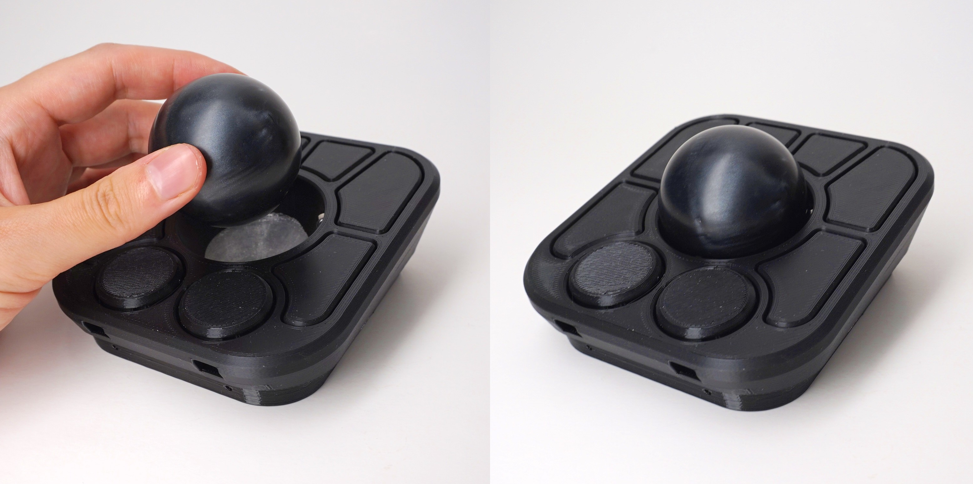
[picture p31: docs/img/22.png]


## Step 23 (OPTIONAL): Screw the Wedge to the Top

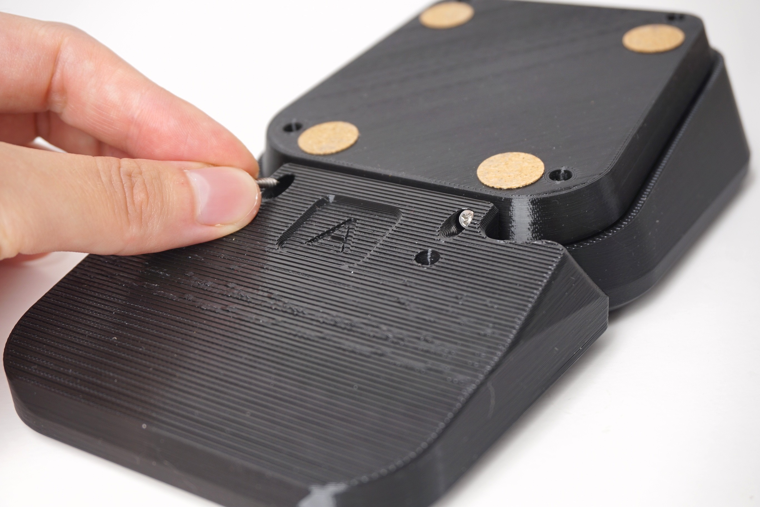
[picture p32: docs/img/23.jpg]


## Step 24: All done!

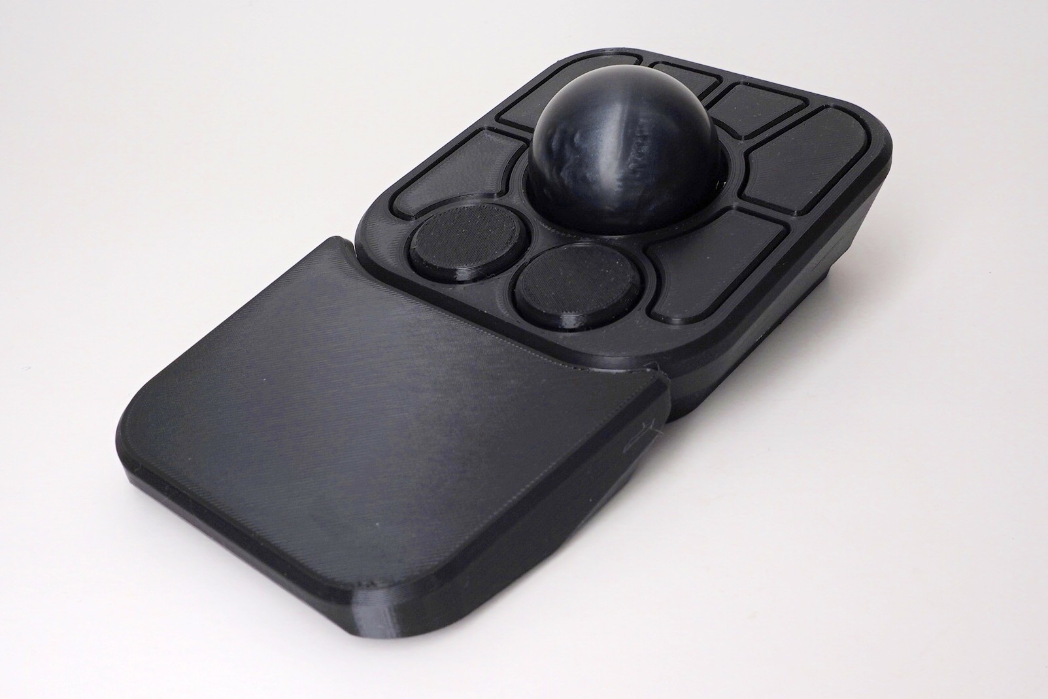
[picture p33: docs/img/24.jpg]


## Post Build Steps:

### Spin the ball to break in the bearings

- Spin the ball around for around 3 minutes to break them initially before any use
- The bearings may take around a week to become fully broken-in/smooth

### Verify the device is working correctly

- Plug the A+ into a computer using a USB-C cable
- Move the ball around, it should move the cursor

<div class="tooltip info">
  <span class="icon">ℹ️</span>
  <span><strong>Info:</strong> The default keymap for the A+ is <a href="../appendices/manual/#default-keymap">here</a>.</span>
</div>

### Check out Post Build FAQ
- [Post Build FAQ](https://help.ploopy.co/?docs=where-can-i-find-mods-for-my-ploopy-device)
- Contains various information about things you can do after initial assembly!

<div class="tooltip info">
  <span class="icon">ℹ️</span>
  <span><strong>Info:</strong> If the device is not working, consult our <a href="https://help.ploopy.co/checklist-v2/">troubleshooting guide</a> for further steps.
</div>

<!--
<div class="tooltip tip">
  <span class="icon">💡</span>
  <span><strong>Tip:</strong> Here's an interesting piece of info!</span>
</div>

<div class="tooltip warning">
  <span class="icon">🚨</span>
  <span><strong>Warning:</strong> Here's a warning!</span>
</div>

<div class="tooltip info">
  <span class="icon">ℹ️</span>
  <span><strong>Info:</strong> Here's some cool stuff!</span>
</div>
-->

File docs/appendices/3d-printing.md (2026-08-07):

# Appendix B: 3D printed parts

## Buying 3D-printed parts from us

Not everyone has access to a 3D-printer. [That's why we sell fully-assembled A+ Trackballs](https://ploopy.co/product-category/trackball/aplus/). Here's why that's great for you:

- You get all of the 3D-printed parts, guaranteed free of manufacturing defects
- You won't waste time spending hours tweaking settings
- We guarantee it will fit together *perfectly*

Consider it. You're a smartie. You'll get there.

## Printing your own parts

So, you have a printer and want to print your own parts? Great! We don't have specific instructions, since every printer setup is different. All of the STLs are available, and if you need to make tweaks, you can alter the design files.

Here are the settings we use when we print parts. **Note that these settings have only been tested on the Prusa i3 MK2.5S and MK3S.** If you have another printer, you may need to tweak these settings.

- PLA. The geometry of many of the parts is quite complex; trying to use other materials may not result in success.
- 0.20mm layer height. You can go finer than this if you want, but we haven't tested that. Going coarser is not going to work; first, it's going to feel rough on your hand, and second, it won't accurately capture the necessary detail.
- No support material is necessary. If your slicer is showing support material, you didn't orient the parts correctly.
- Orient the pieces so that flat sides are on the build plate.
- We like gyroid for infill pattern, but anything is probably good. Cubic, rectilinear, whatever.
- We use 0.4mm nozzles. We haven't tested other nozzle sizes.

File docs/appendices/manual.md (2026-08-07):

# Appendix E: User Manual

## A+ physical description

### Default keymap

The default keymap for the A+ Trackball is available as a PDF that you can print out for easy reference.

[View keymap](../img/keymap.pdf){: target="_blank" .md-button }

### Wrist rest

If you have a wrist rest for the A+, you can hook it into the case, and the two should stay connected during regular use. If you need the connection to be more secure, however, we've included two screws that you can use to screw the two pieces together. The screws get inserted when the A+ is upside-down.

## Customizing buttons

All buttons can be customized using a web application called "VIA". This includes all of the buttons on other layers.

For now, you'll have to configure VIA to function with the A+ Trackball. It takes about thirty seconds. To do so, [see this information](via.md).

There are lots of tutorials about how to use VIA. Here is an example.

### Example: Changing B4's Functionality

Let's say you want to change B4 from "drag scroll" to being the "mute" button. Here's how to do that:

- Go to the CONFIGURE tab in VIA.
- On the interface, click on B4 (it should say DragScroll on it). It should start pulsating.
- On the bottom half of the screen, click the MEDIA tab (it should be below BASIC).
- Click on Mute. You should see the text on B4 change from DragScroll to Mute.

And you're done! Now, when you click the B4 button the A+, it should mute or unmute your audio.

## Factory-resetting the A+

If the A+ somehow gets into a state where it can no longer work, the solution is easy.

[Using the default firmware](https://github.com/ploopyco/aplus-trackball/tree/main/firmwares/aplus.uf2), follow the instructions in [the firmware programming guide](programming.md#putting-the-ploopy-device-into-bootloader-mode) to load it onto the A+. After that, the A+ should be reset back to its factory settings.

## Questions?

If you have any other questions, you can find many answers on the [Ploopy Help Center](https://help.ploopy.co/).

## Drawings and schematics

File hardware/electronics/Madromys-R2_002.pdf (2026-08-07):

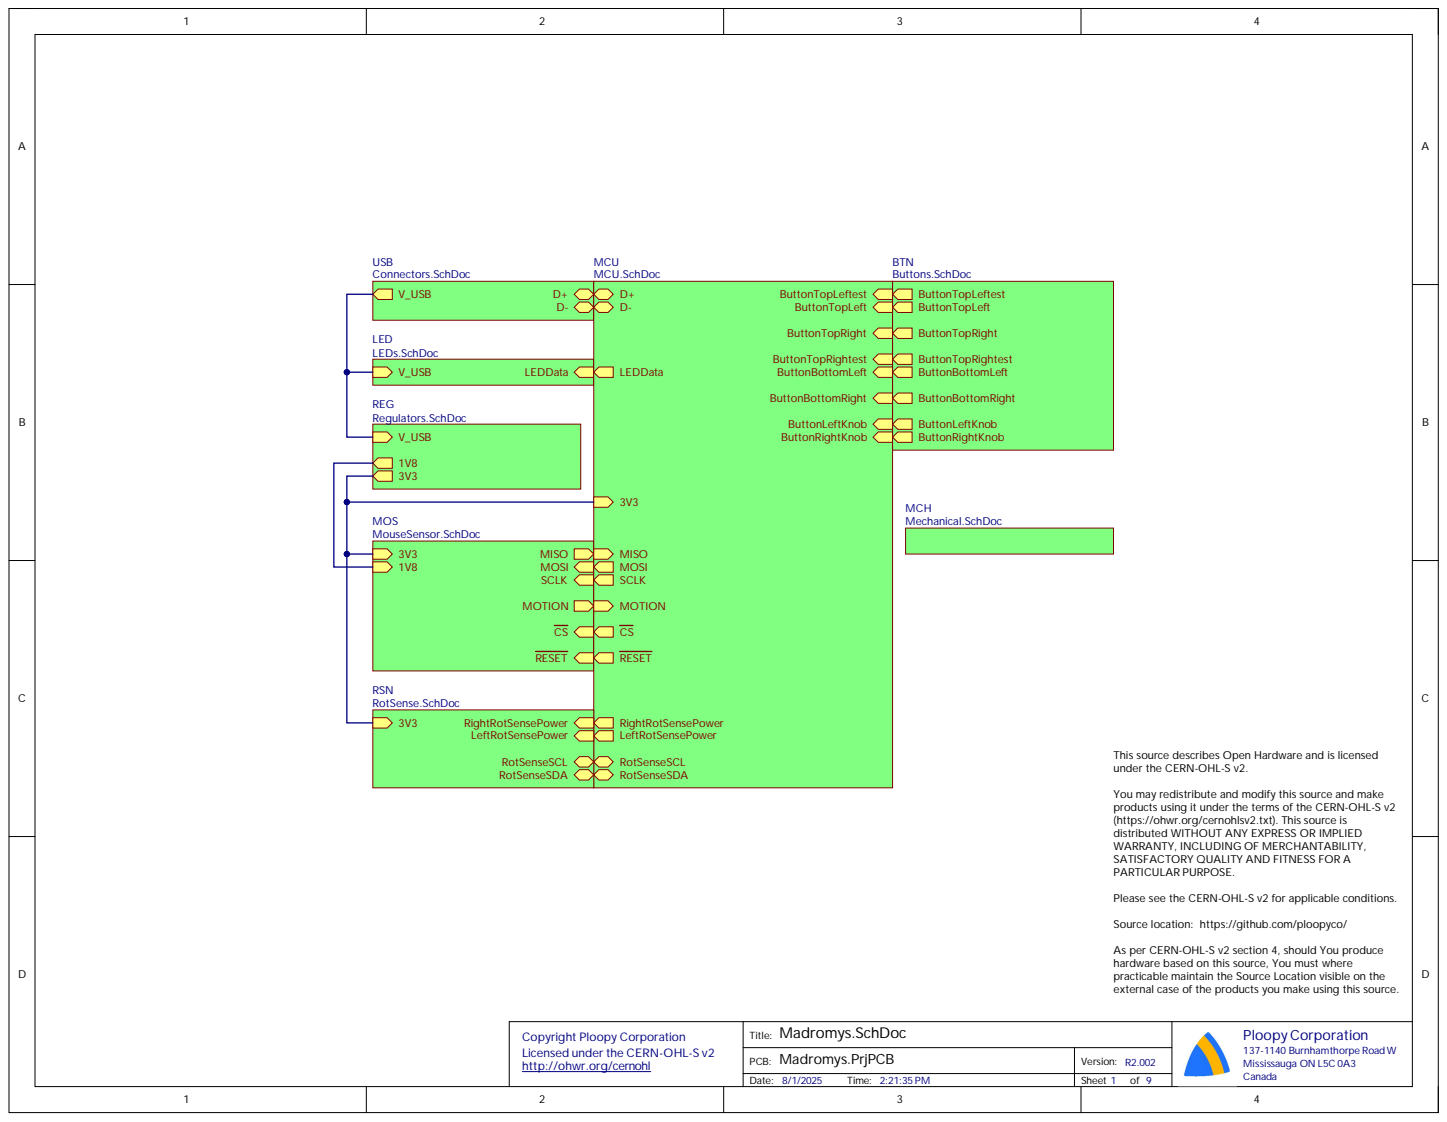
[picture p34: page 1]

This source describes Open Hardware and is licensed
under the CERN-OHL-S v2.

You may redistribute and modify this source and make
products using it under the terms of the CERN-OHL-S v2
(https://ohwr.org/cernohlsv2.txt). This source is
distributed WITHOUT ANY EXPRESS OR IMPLIED
WARRANTY, INCLUDING OF MERCHANTABILITY,
SATISFACTORY QUALITY AND FITNESS FOR A
PARTICULAR PURPOSE.

Please see the CERN-OHL-S v2 for applicable conditions.

Source location: https://github.com/ploopyco/

As per CERN-OHL-S v2 section 4, should You produce
hardware based on this source, You must where
practicable maintain the Source Location visible on the
external case of the products you make using this source.

Copyright Ploopy Corporation
Licensed under the CERN-OHL-S v2
http://ohwr.org/cernohl

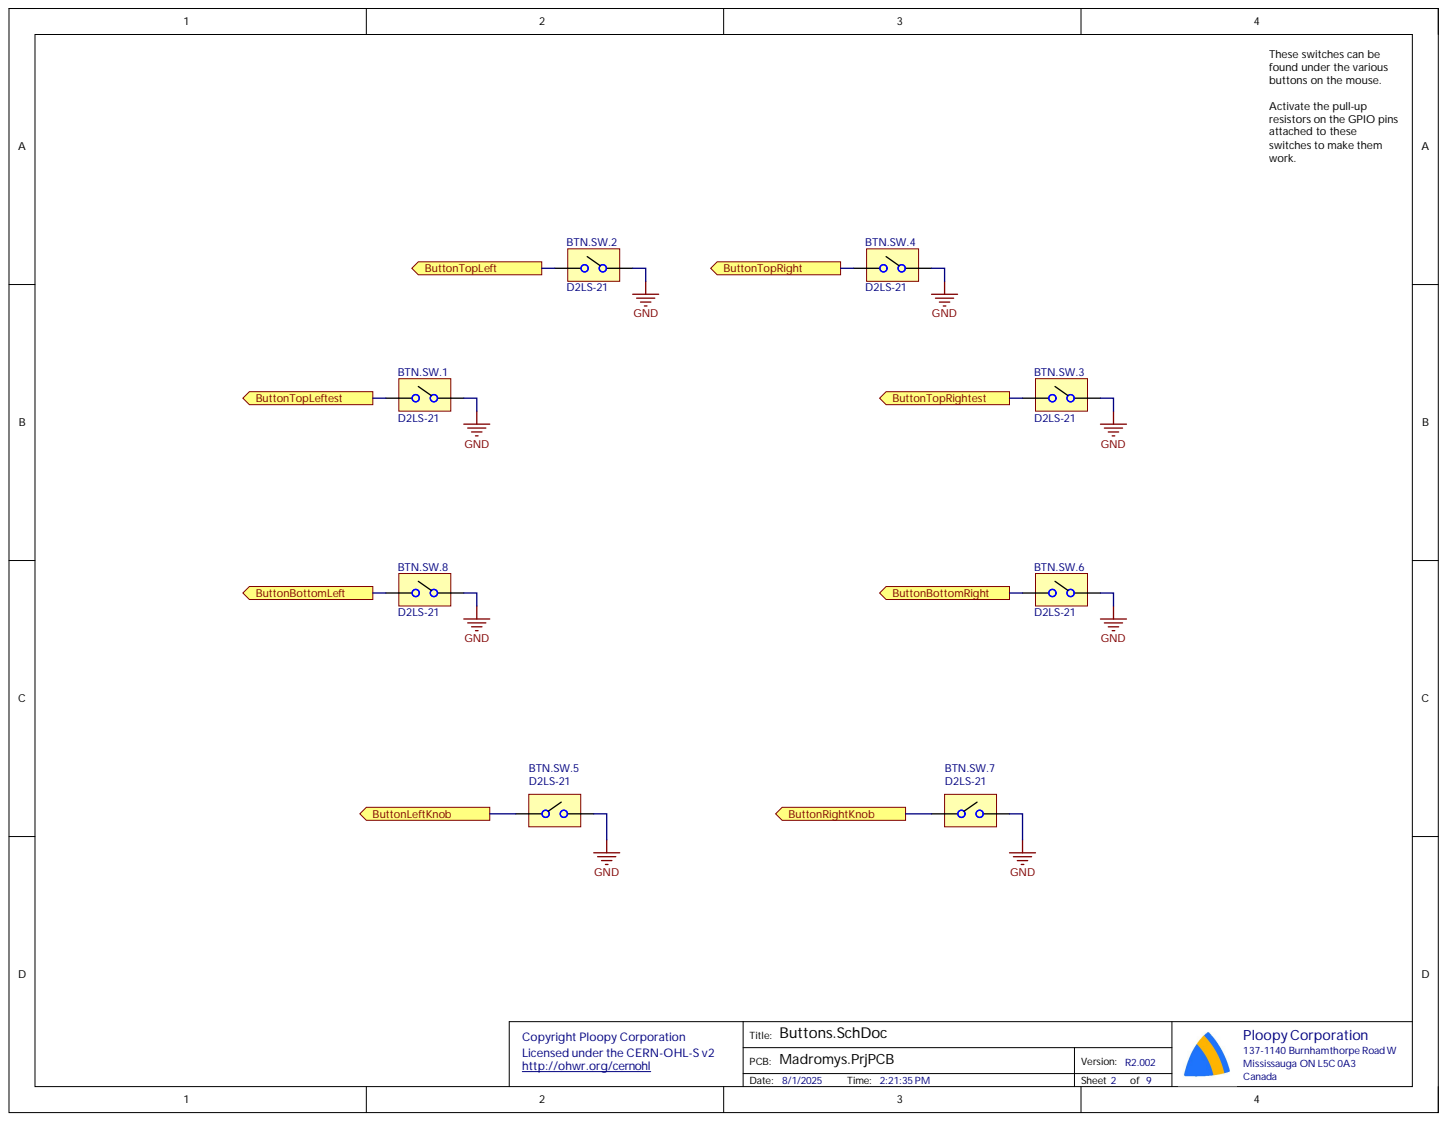
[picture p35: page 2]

These switches can be
found under the various
buttons on the mouse.

Activate the pull-up
resistors on the GPIO pins
attached to these
switches to make them
work.

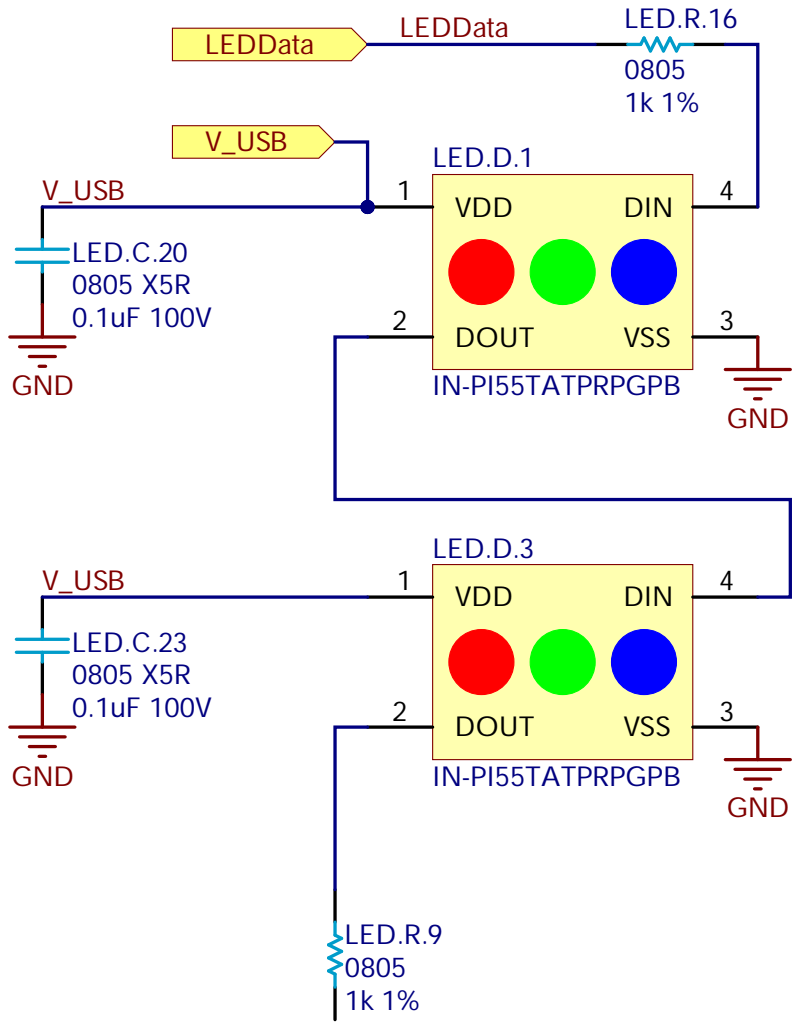
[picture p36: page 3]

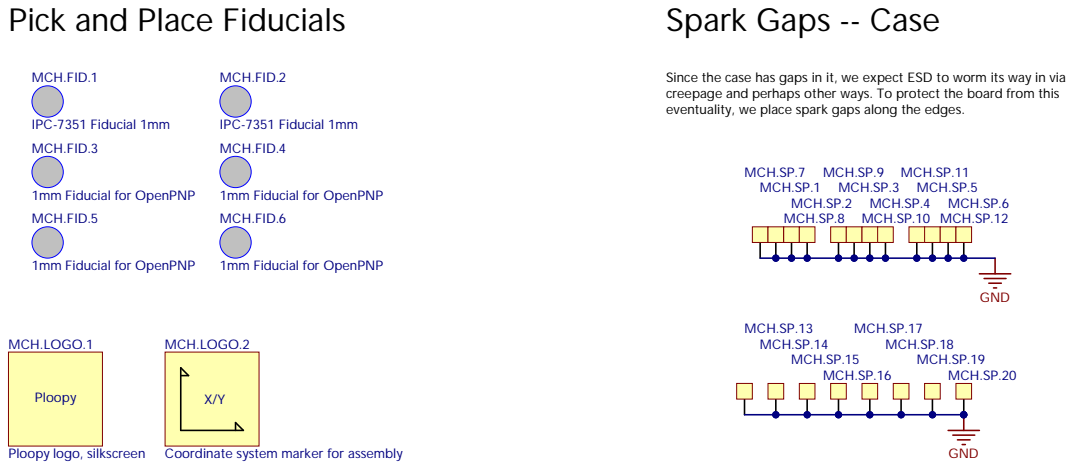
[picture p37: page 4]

Pick and Place Fiducials

Spark Gaps -- Case MCH.SP.7 MCH.SP.1 MCH.SP.8 MCH.SP.2 MCH.SP.9 MCH.SP.3 MCH.SP.10 MCH.SP.4 MCH.SP.1

Since the case has gap
creepage and perhap
eventuality, we place s

s other ways. To protect the board from this
park gap

pect ESD to worm its way in via

Coordinate system marker for assem

Cop
Licensed under the CE
http

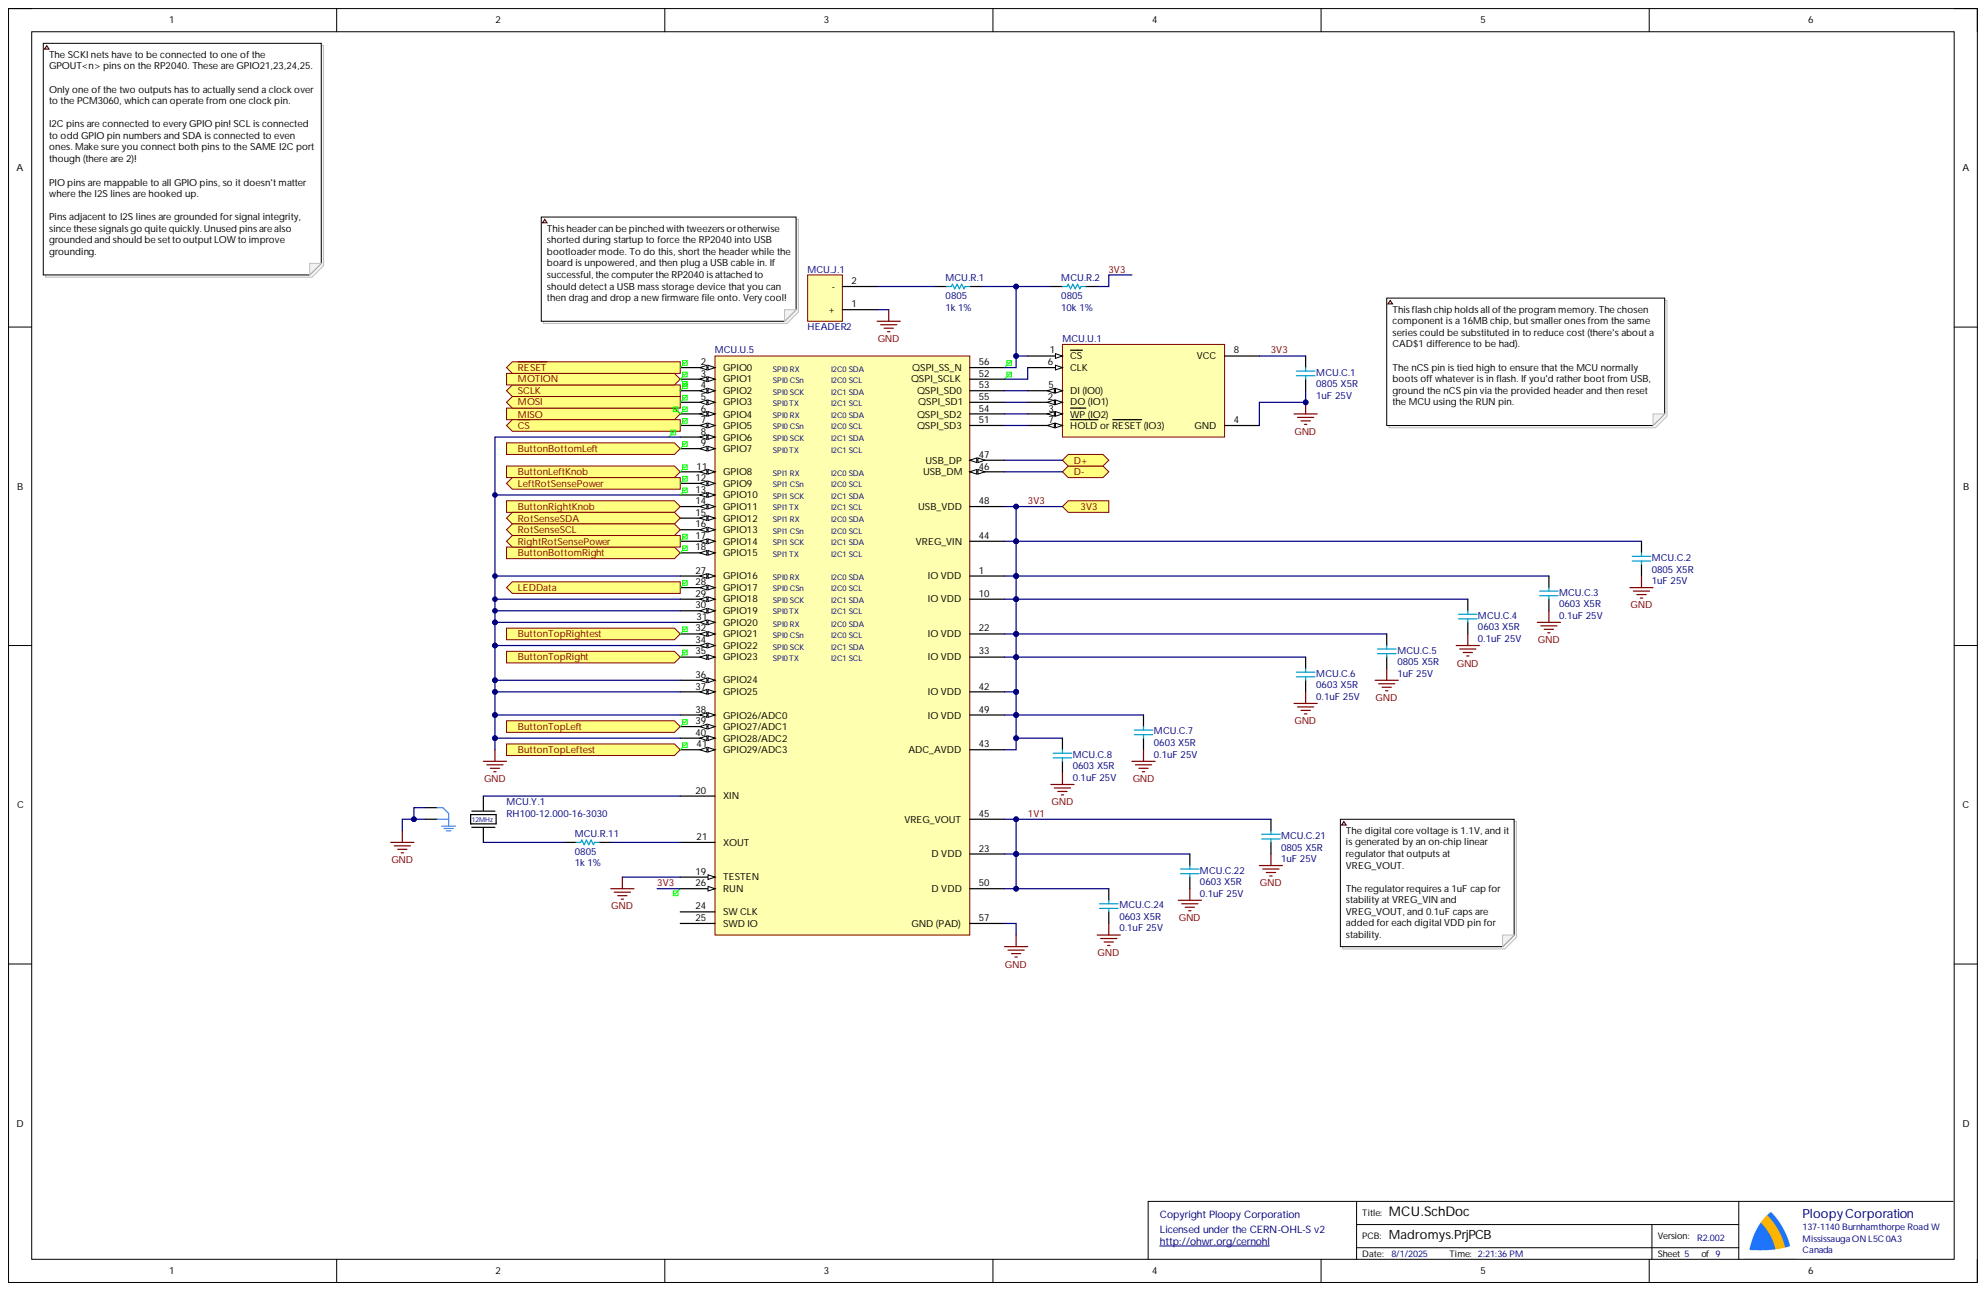
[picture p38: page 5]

The SCKI nets ha

But t onR i ghtKno b R o tSenseSDA R o tSenseSC L R i ght R o tSenseP o we r But t onBo t t o m R i g h t

LEDDa t a

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

PC B : Madr omy s.P rj PC B | V e rsion : R 2 . 002

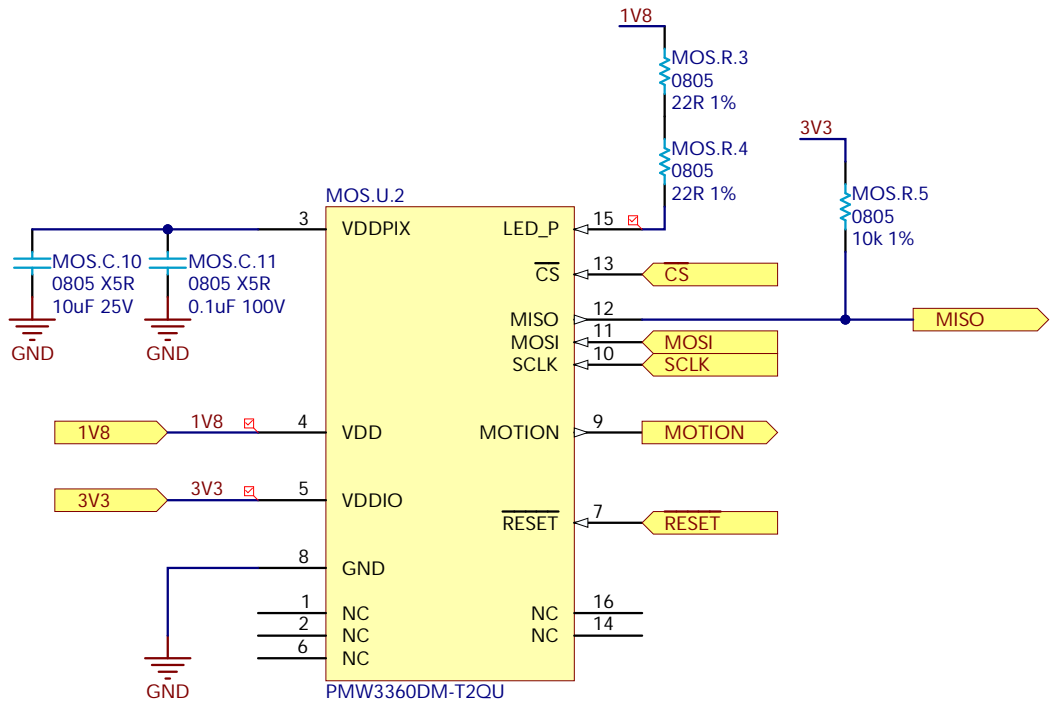
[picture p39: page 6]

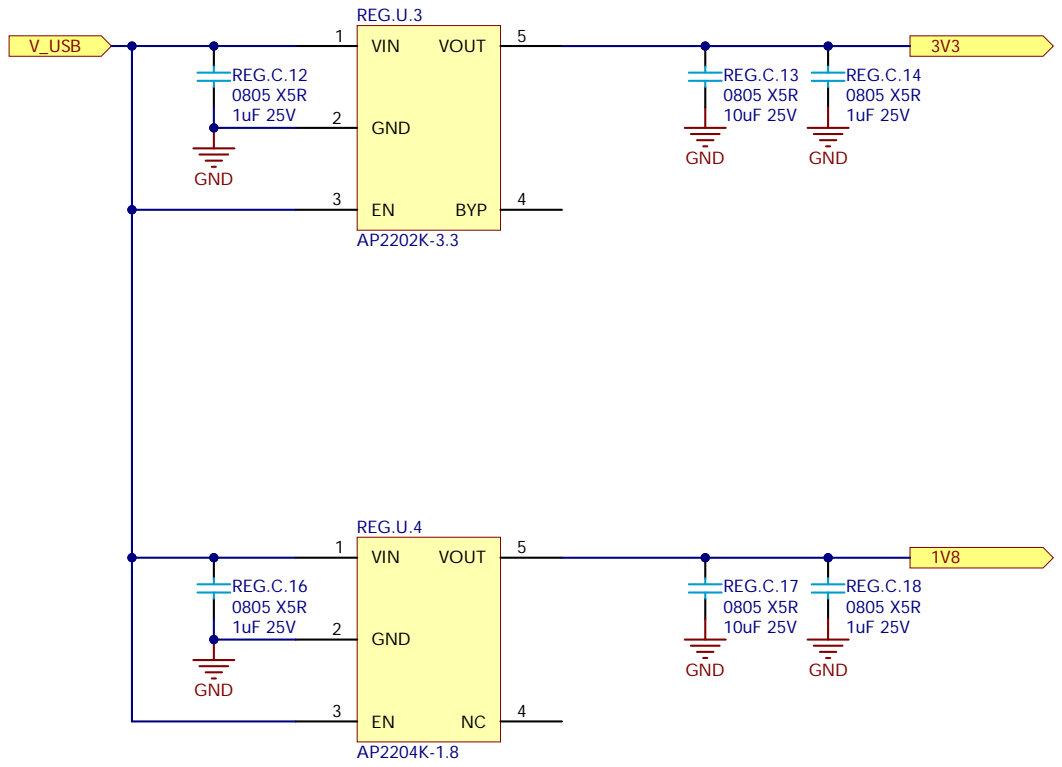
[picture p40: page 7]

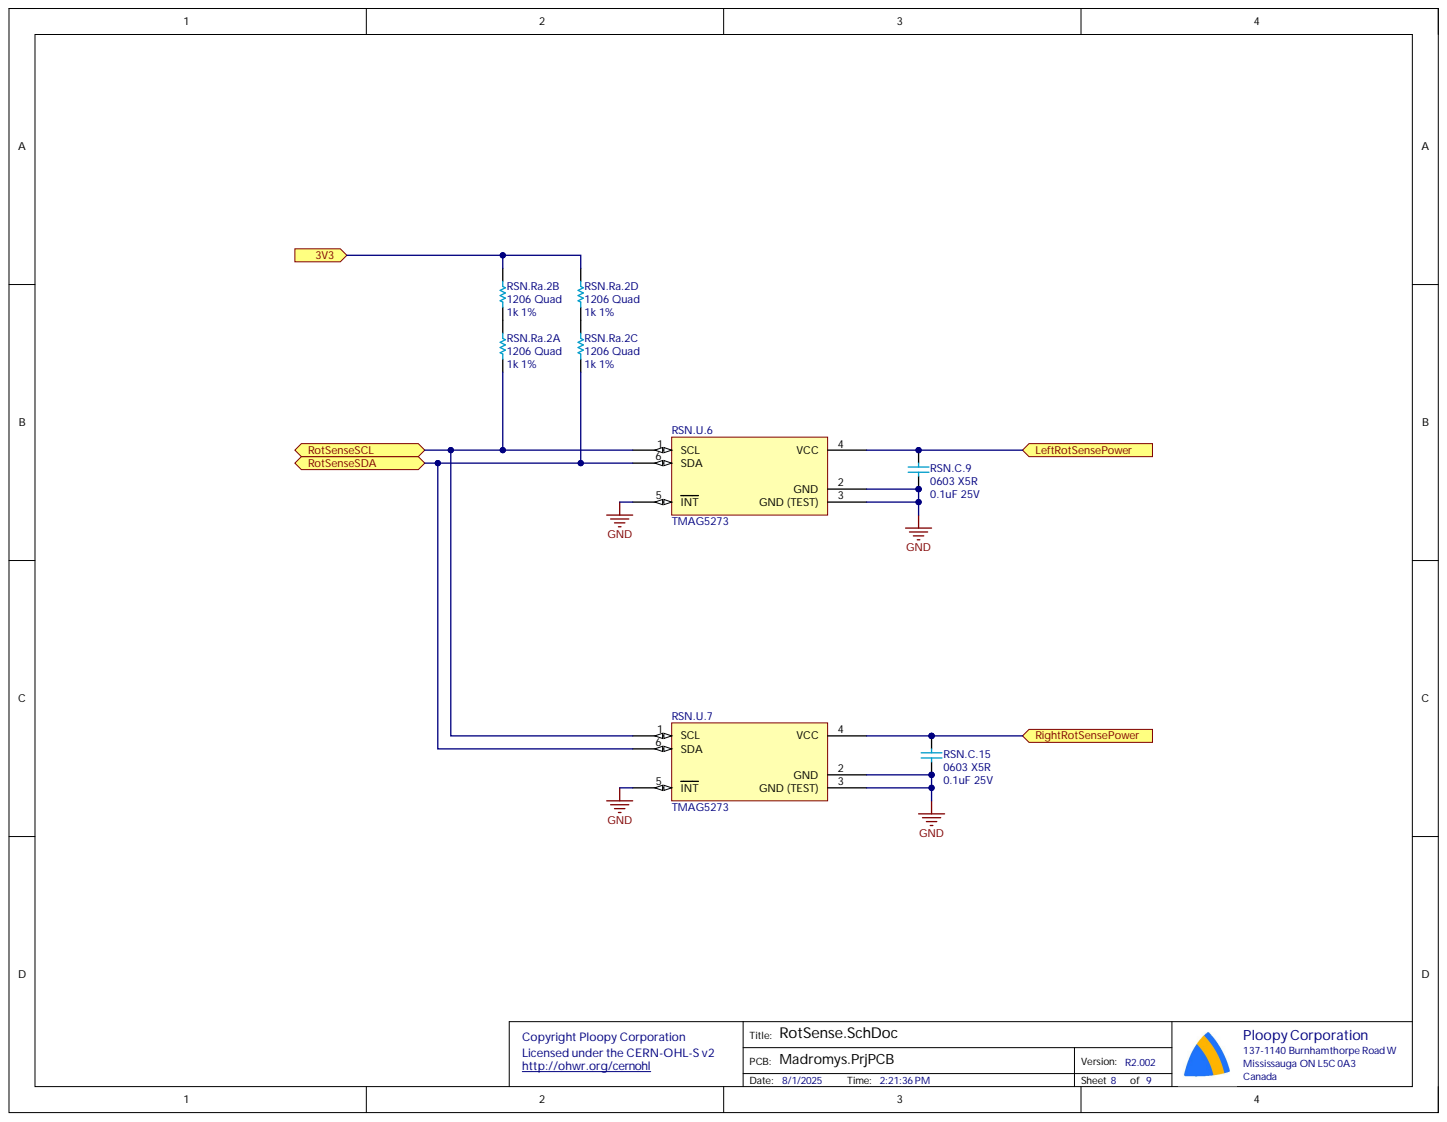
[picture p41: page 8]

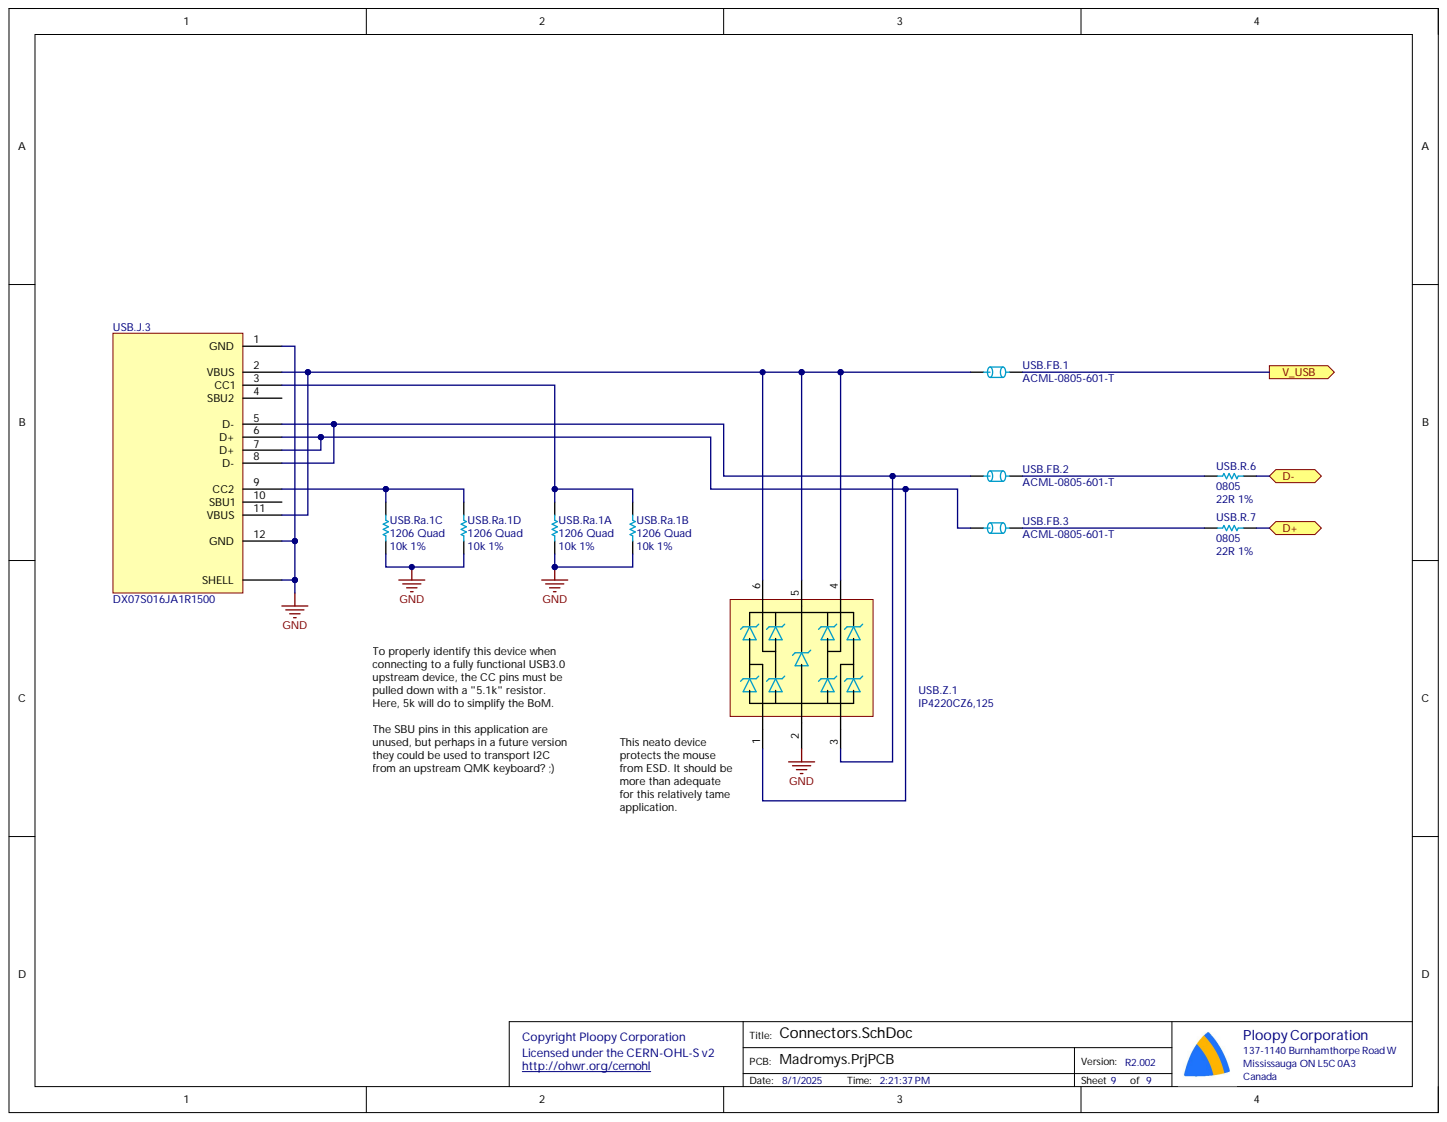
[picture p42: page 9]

To properly identify this device when
connecting to a fully functional USB3.0
pulled down with a "5.1k" resistor.
Here, 5k will do to sim

The SBU pins in this ap
unused, but perhap
they could be used to trans
from an up

This neato device protects the mouse

from ESD. It should be more than adequate

for this relatively tame

Cop
Licensed under the CE
http

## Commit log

2026-08-07 initial open source release
    [Aplus-RevA-NoLogo.STEP, Aplus-RevA-NoLogo.STL, Buttons.SchDoc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]
2026-08-19 Fix broken link (typo - vs _) in PCB documentation
